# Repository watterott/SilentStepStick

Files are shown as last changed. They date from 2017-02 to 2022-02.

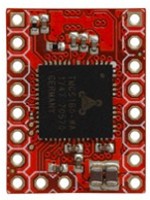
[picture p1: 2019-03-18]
hardware/SilentStepStick-TMC5160_v13.jpg

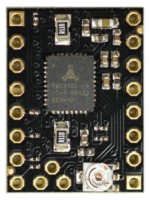
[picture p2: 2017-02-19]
hardware/SilentStepStick-TMC2100_v13.jpg

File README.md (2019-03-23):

# SilentStepStick
The Silent-Step-Stick is a Stepper Motor Driver Board for 2-Phase Motors based on [Trinamic](https://www.trinamic.com) Motor Drivers.

* Hardware compatible with [StepStick](https://reprap.org/wiki/StepStick) and [Pololu A4988](https://www.pololu.com/product/1182)
* [Trinamic](https://www.trinamic.com) stepper motor driver (chopper drive / constant current drive) with
  * Automatic standby current reduction
  * **microPlyer** - microstep interpolator for increased smoothness of microstepping
  * **stealthChop** - for quiet operation and smooth motion
  * **spreadCycle** - highly dynamic motor control chopper
* Open-Source and released under the [Creative Commons Attribution Share-Alike License](https://creativecommons.org/licenses/by-sa/4.0/).
* **[Documentation on learn.watterott.com](https://learn.watterott.com)**

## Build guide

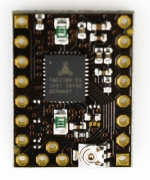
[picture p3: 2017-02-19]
hardware/SilentStepStick-TMC2100_v10.jpg

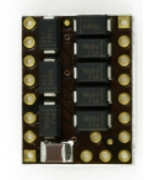
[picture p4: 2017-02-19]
hardware/StepStick-Protector_v10.jpg

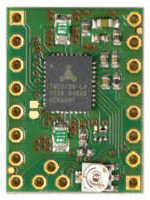
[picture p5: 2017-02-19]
hardware/SilentStepStick-TMC2130_v11.jpg

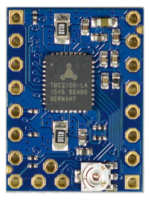
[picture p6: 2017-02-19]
hardware/SilentStepStick-TMC2100_v13_5V.jpg

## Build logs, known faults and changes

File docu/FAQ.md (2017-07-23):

# Frequently Asked Questions

## Is the SilentStepStick 100% compatible with a StepStick or Pololu A4988?
The SilentStepStick is hardware/pin compatible with StepStick and Pololu A4988 drivers.
However the TMC21x0 has different and more settings, which can be set via the CFG/MS pins and the **DIR pin is inverted** (direction).
The TMC21x0 config pins also know three states: low (GND), high (VIO) and open (unconnected).
The TMC2130 can be configured via CFG pins or [SPI](https://en.wikipedia.org/wiki/Serial_Peripheral_Interface_Bus) and the TMC2208 via CFG pins or [UART](https://en.wikipedia.org/wiki/Universal_asynchronous_receiver/transmitter).

## Which operating mode should I use?
For most cases (except a 3D printer extruder) the **1/16 stealthChop** mode (TMC2100: CFG1=open CFG2=open, default on TMC2208) is suitable.
If you have problems like step losses then you can use a [slower acceleration](https://www.youtube.com/watch?v=c3v9E1AwDBE) or a bit higher current setting in stealthChop 
or you can use the more powerful and louder **1/16 spreadCycle** mode (TMC2100: CFG1=GND CFG2=open).

#### Boards with USB Power Supply
Only applicable for SilentStepSticks with variable 3-5V logic voltage (VIO):
If you use a control board with USB power supply (like Arduino + RAMPS) then always ensure that the motor voltage (VM) is present, when you connect the board via USB.
Otherwise the TMC2xxx is not powered via the internal voltage regulator and a high current can flow into VIO or the IOs and this can damage the internal logic.
As safety workaround you can disconnect the 5V signal in the USB cable, so that the board cannot be powered over USB.

#### RAMPS 1.4 and RUMBA Notes
For most cases the **1/16 stealthChop** mode is suitable and we recommend the TMC2100 SilentStepStick with 5V for RAMPS and RUMBA boards, because they use 5V logic.
If you remove all jumpers (or open all switches) for MS1+MS2+MS3 on the RAMPS/RUMBA, then the SilentStepStick TMC2100 driver will be in **1/16 spreadCycle mode** (CFG1=GND CFG2=open), because there is a pull-down resistor on MS1 on the RAMPS/RUMBA.
The pull-down is 100k and in most cases it will set the driver in spreadCycle mode correctly. However if there are problems then short CFG1 to GND or replace the resistor with one which is 30k or less.
If you have not an original [RAMPS 1.4](http://reprap.org/wiki/RAMPS_1.4) or [RUMBA](http://reprap.org/wiki/RUMBA), then your schematics can be different and you have to check the MS-Pin configurations on you board.

## Can I use a stepper motor with a lower voltage than the driver motor supply voltage?
Yes, because the TMC2xxx drivers use a chopper drive circuit to generate a constant current in each winding (motor phase) rather than applying a constant voltage.

## What is the difference between SilentStepSticks with 3-5V and 5V logic voltage?
The SilentStepSticks with a variable logic voltage (VIO) of 3-5V use the internal linear regulator of the TMC2xxx to generate from the motor voltage (VM) a 5V voltage for the internal digital and analog circuit (about 20mA).
Because it is a linear voltage regulator the power dissipation depends on the motor voltage (high motor voltage = high power dissipation/heat).
The 5V logic SilentStepSticks do not use the internal voltage regulator of TMC2xxx and therefor only a 5V supply voltage for VIO is possible and VM has not to be present before VIO.
Further infos about power-up and down can be found [here](https://github.com/watterott/SilentStepStick/blob/master/docu/FAQ.md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).

Power dissipation of the internal voltage regulator:
* 0.1W @ VM=12V
* 0.3W @ VM=24V
* 0.6W @ VM=36V
* 0.8W @ VM=45V

## Is the TMC2130 SilentStepStick in standalone mode like a TMC2100 SilentStepStick?
The configuration for TMC2130 in standalone mode (SPI jumper closed) is set via the CFG pins like the TMC2100.
On the TMC2100 SilentStepSticks the CFG0 pin is set to GND as default and this sets the chopper off time to 140 Tclk (most universal choice).
In contrast on the TMC2130 SilentStepSticks the CFG0 pin (also SDO) is open as default and this sets the chopper off time to 332 Tclk.
On the TMC2130 SilentStepSticks the CFG3 pin is also connected to the pin header and should be left unconnected/open (external reference voltage on AIN) in standalone mode.

## Where can I find more information on the settings and operation modes?
More information can be found in the [SilentStepStick schematics (PDF files)](https://github.com/watterott/SilentStepStick/tree/master/hardware) and
[TMC2100 datasheet](http://www.trinamic.com/products/integrated-circuits/details/tmc2100/),
[TMC2130 datasheet](http://www.trinamic.com/products/integrated-circuits/details/tmc2130/) or
[TMC2208 datasheet](http://www.trinamic.com/products/integrated-circuits/details/tmc2208-la/).

A configuration tool for the TMC2208 can be found [here](https://github.com/watterott/SilentStepStick/tree/master/software/ScriptCommunicator#tmc2208-configurator).

Detailed information about the operating modes:
[stealthChop](https://www.trinamic.com/technology/adv-technologies/stealthchop/) and
[spreadCycle](https://www.trinamic.com/technology/adv-technologies/spreadcycle/).

#### Infos and Installation Guides for 3D Printers
* General: [English](http://reprap.org/wiki/TMC2100),
           [German](http://reprap.org/wiki/TMC2100/de),
           [French](http://reso-nance.org/wiki/materiel/silentstepstick/accueil),
           [Russian](http://3deshnik.ru/blogs/akdzg/chto-zhe-delat-belami-tmc2100),
           [Japanese](http://3dp0.com/silentstepstick)
* [Ultimaker UMO + TMC2100 (English)](https://ultimaker.com/en/community/11571-step-by-step-installation-of-silentstepstick-drivers-on-umo)
* [Ultimaker UMO + TMC2130 (English)](https://ultimaker.com/en/community/20090-step-by-step-installation-of-sss-tmc2130-on-umo)
* [TMC2130 (English)](http://hackaday.com/2016/09/30/3d-printering-trinamic-tmc2130-stepper-motor-drivers-shifting-the-gears/)

## How to set the stepper motor current?
The best way to set the motor current is by measuring the voltage on the ```Vref``` pin (0...2.5V) and
adjusting the voltage with the potentiometer.
The maximum motor current is 1.77A RMS and is set via the 0.11Ohm sense resistors.

```Irms = (Vref * 1.77A) / 2.5V = Vref * 0.71```

```Vref = (Irms * 2.5V) / 1.77A = Irms * 1.41 = Imax```

```Vref``` -> Voltage on Vref pin

```Irms``` -> RMS (Root Mean Square) current per phase (Irms = Imax / 1.41)

```Imax``` -> Maximum current per phase (Imax = Irms * 1.41)

**Example:**
A voltage of 1.0V on Vref sets the motor current to 0.71A RMS.

**Note:**
On some stepper motor drivers the maximum current (e.g. A4988) is set via Vref and on others the RMS current (e.g. TMC2100).
The Trinamic drivers have an automatic thermal shutdown (at about 150°C) if the chip gets to hot.

## What to consider when turning the power supply on or off?
**Power on:**

*SilentStepSticks with variable 3-5V logic voltage:*
The motor voltage VM should come up first and then the logic voltage VIO, because the internal logic of the TMC2xxx driver is powered from VM.

*SilentStepSticks with 5V logic voltage:*
There is no special power up sequence needed.

Only after the logic voltage VIO is present and stable, the driver inputs (STEP, DIR, EN, CFG...) can be driven with a high level.

A step pulse (moving) should only be done after the motor voltage VM is present and stable.

Because the motor voltage VM is a strong power supply with a high voltage, also ensure that there cannot occur voltage spikes on power up.
See [Pololu: Understanding Destructive LC Voltage Spikes](https://www.pololu.com/docs/0J16/all).

**Power off:**

*SilentStepSticks with variable 3-5V logic voltage:*
The logic voltage VIO should turned off at first and then the motor voltage VM, because the internal logic of the TMC2xxx driver is powered from VM.

*SilentStepSticks with 5V logic voltage:*
There is no special power off sequence needed.

If the motor is running/moving, then it is not allowed to switch off the power supply. Always make sure that the motor stands still on shutting down, otherwise the TMC2xxx driver can get damaged.

An **emergency stop** can be realized, when the EN/CFG6 pin is set to VIO (high). This will switch off all power drivers and will put the motor into freewheeling.
See also: [SilentStepStick Protector with flyback diodes](https://github.com/watterott/SilentStepStick#shop)

## The motor makes noise in spreadCycle mode when it is not moving?
A motor supply voltage of 12V is in most cases to low and in general the sound gets quieter if the motor supply voltage is above 18V.
As workaround it is possible to activate the TMC21x0 automatic current reduction on standstill. This is done by not connecting the EN pin (EN=open).

## How to control the Trinamic stepper motor driver?
The SilentStepStick has a normal step+direction interface.
You set the direction with the DIR pin and on every pulse on the STEP pin the motor will move one step.
Here you can find an [Arduino example](https://github.com/watterott/SilentStepStick/tree/master/software) and [Arduino library](http://www.airspayce.com/mikem/arduino/AccelStepper/) (interface=DRIVER).

## Is it possible to connect the CFG pins from different SilentStepSticks?
It is possible to connect the CFG pins from two or more driver boards.
However then the pin state can only be GND (low) or VIO (high). The open state (unconnected) is not possible in this configuration.

## Why is the Trinamic driver chip on the bottom PCB side?
The TMC2xxx chip has a thermal pad on the bottom which is soldered to the PCB.
So the thermal resistance via the chip bottom is better than via the chip top.
That is why the chip is on the bottom PCB side.
A heat sink can be placed directly on the PCB.
Further infos [here](https://www.youtube.com/watch?time_continue=145&v=mYuZqx8xwTg).

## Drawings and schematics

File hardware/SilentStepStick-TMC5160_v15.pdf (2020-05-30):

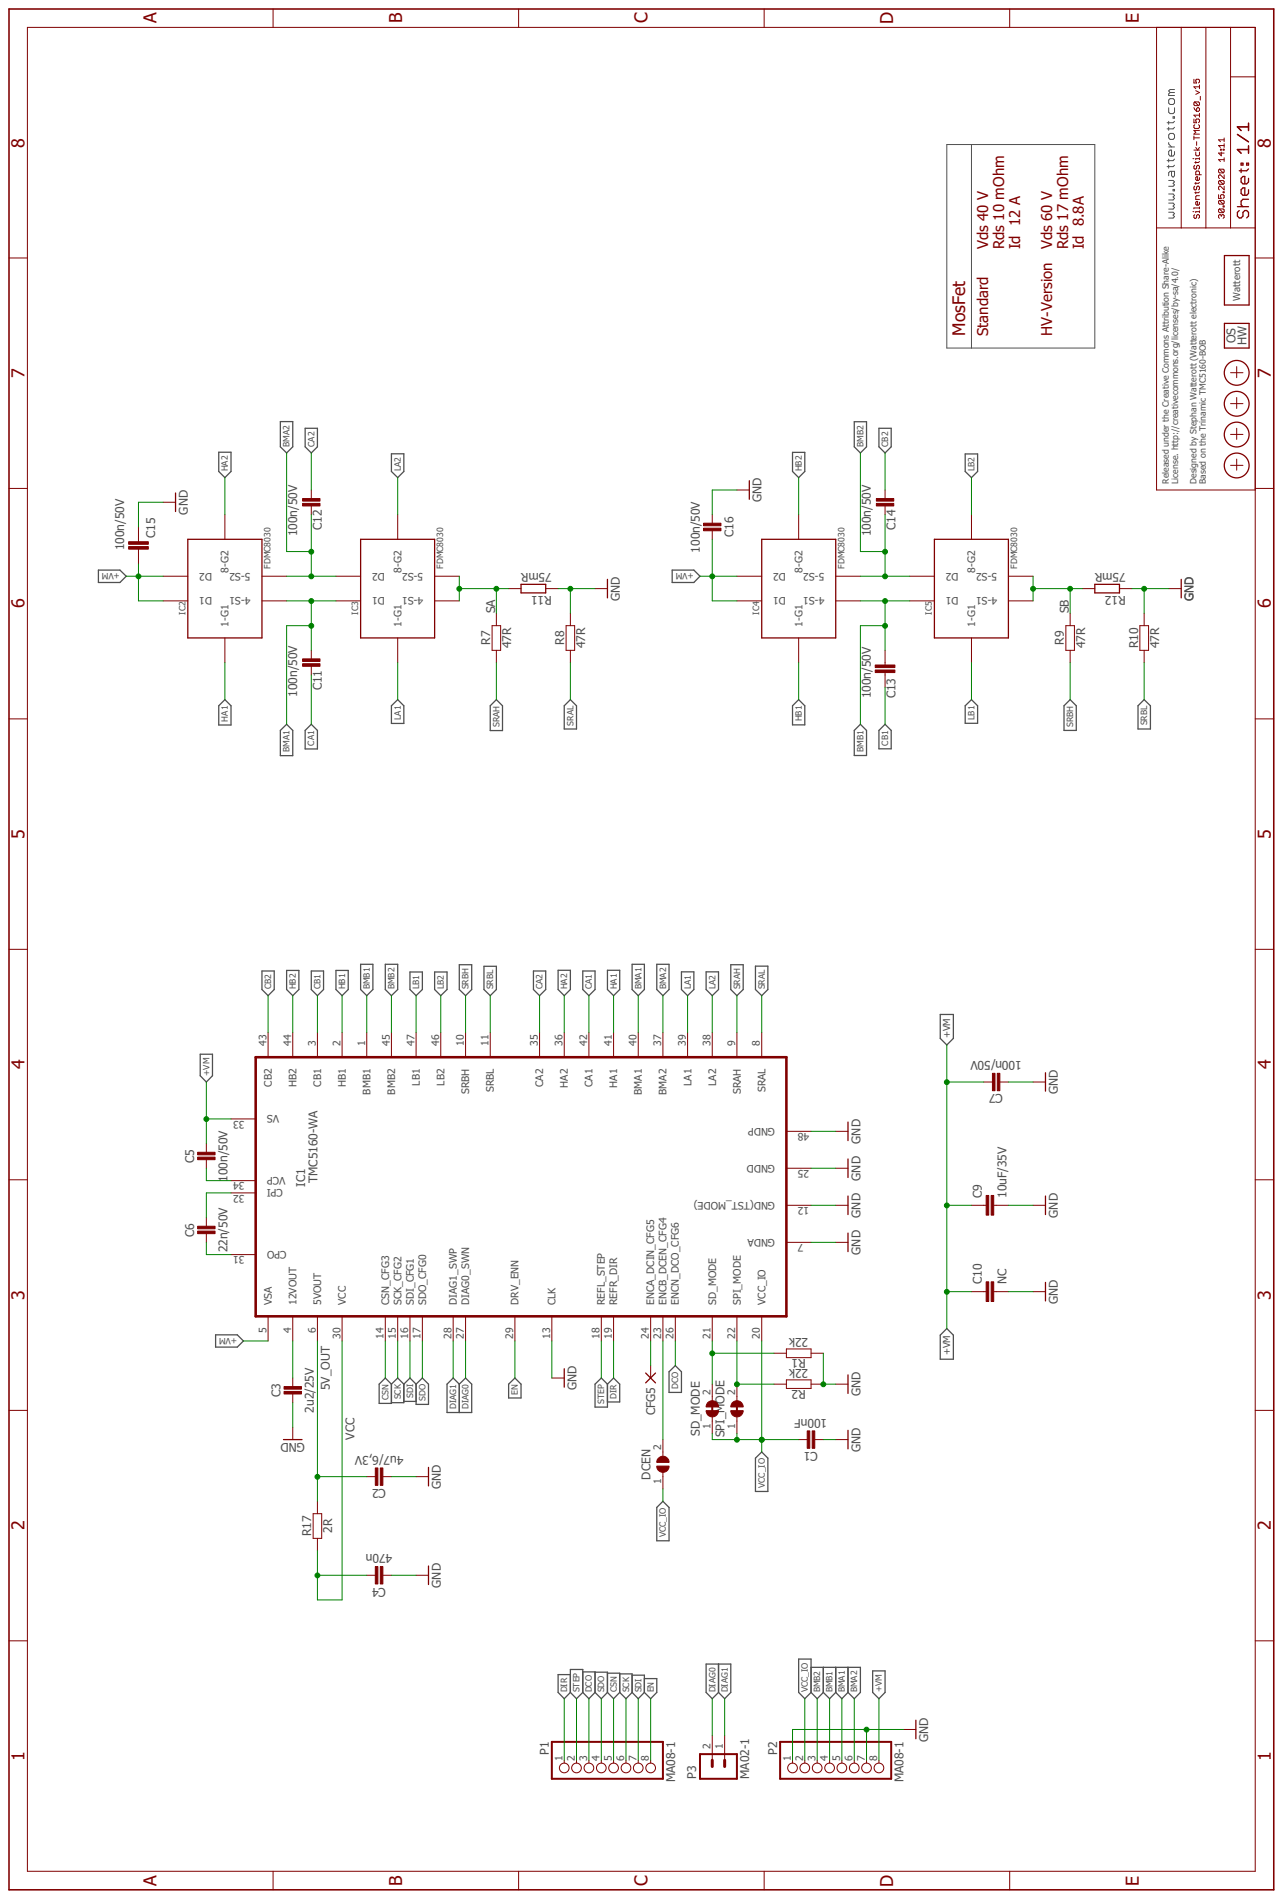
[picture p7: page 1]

MosFet Standard HV-Version

Released under the Creative Commons Attribution Share-Alike

License. http://creativecommons.org/licenses/by-sa/4.0/ Designed by Stephan Watterott (Watterott electronic) Based on the Trinamic TMC5160-BOB

10uF/35V NC GND GND GND

GND GND

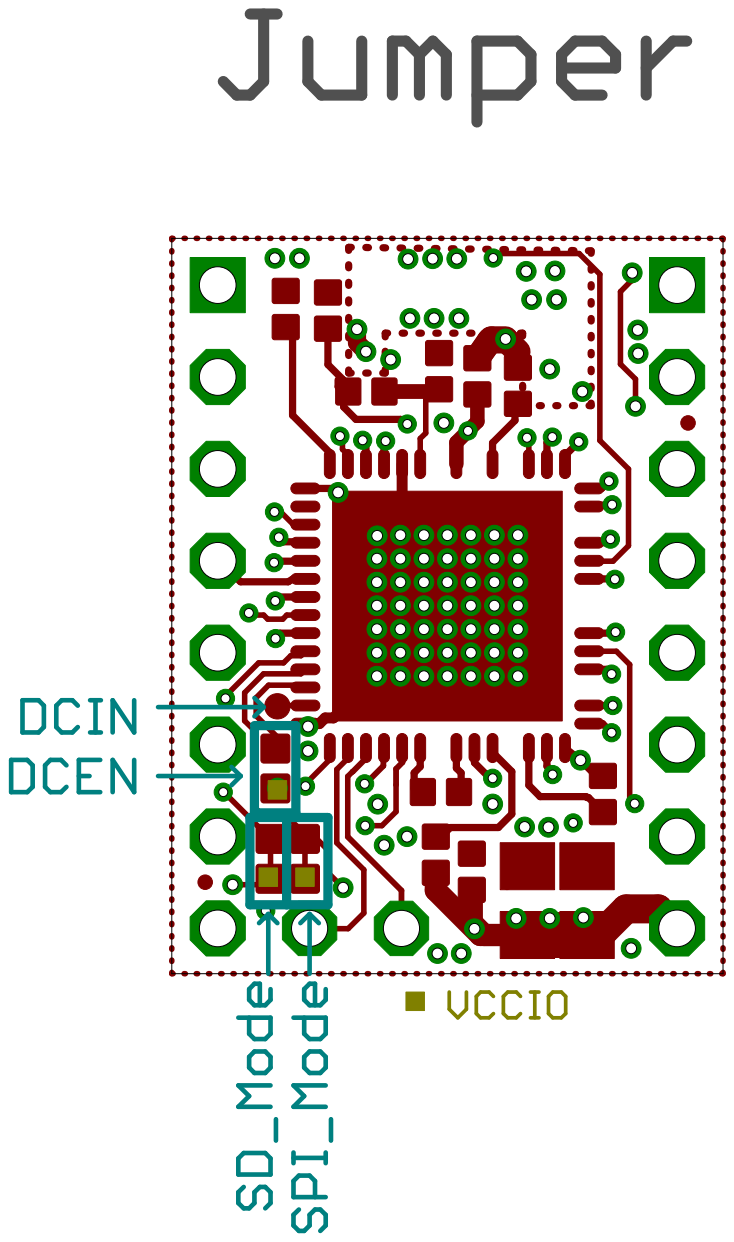
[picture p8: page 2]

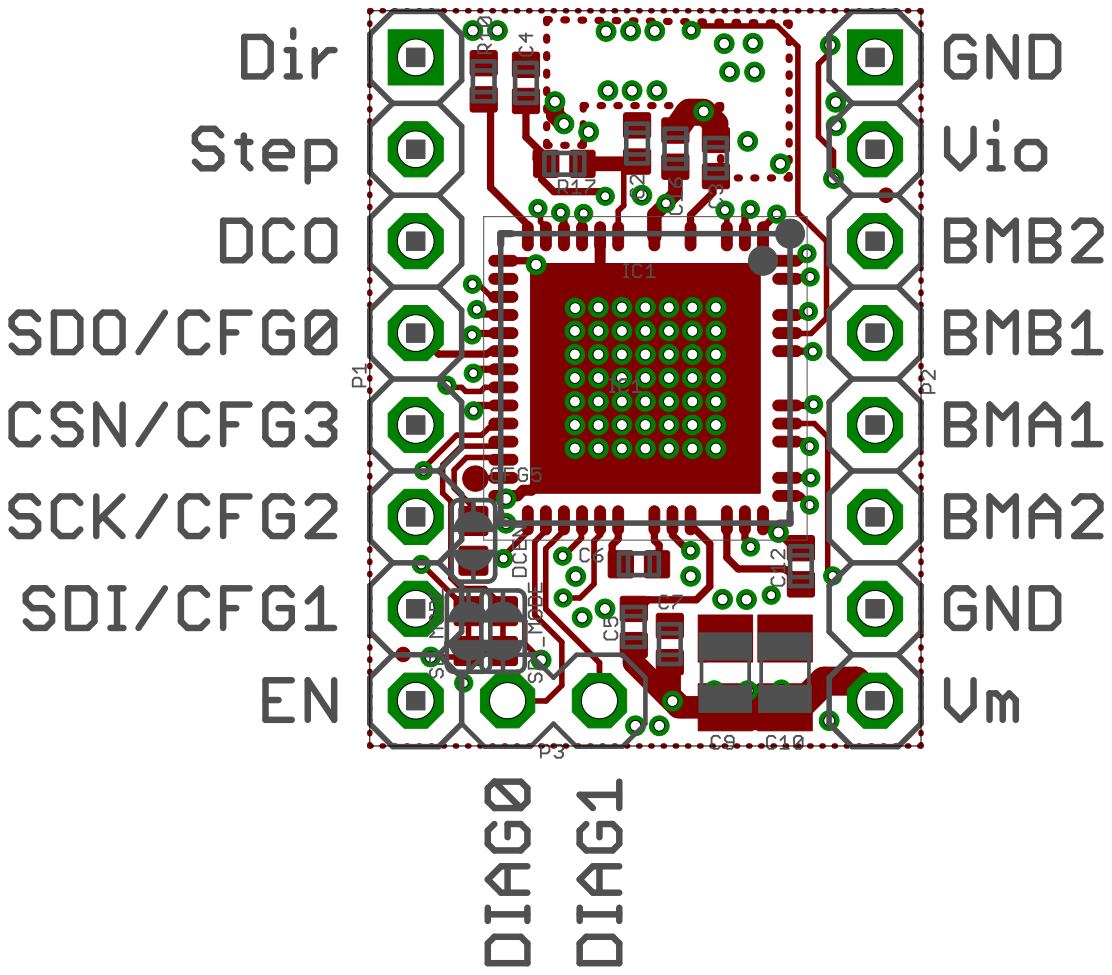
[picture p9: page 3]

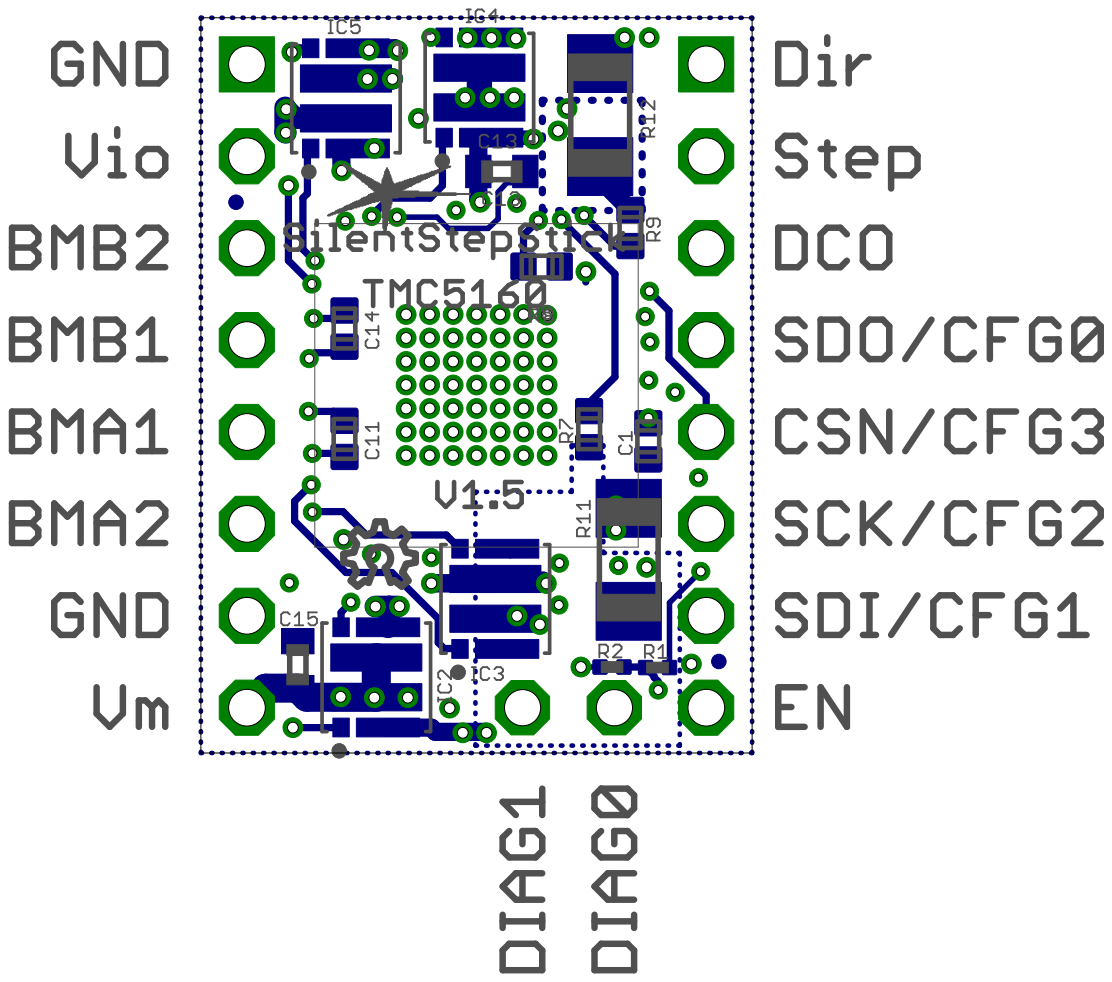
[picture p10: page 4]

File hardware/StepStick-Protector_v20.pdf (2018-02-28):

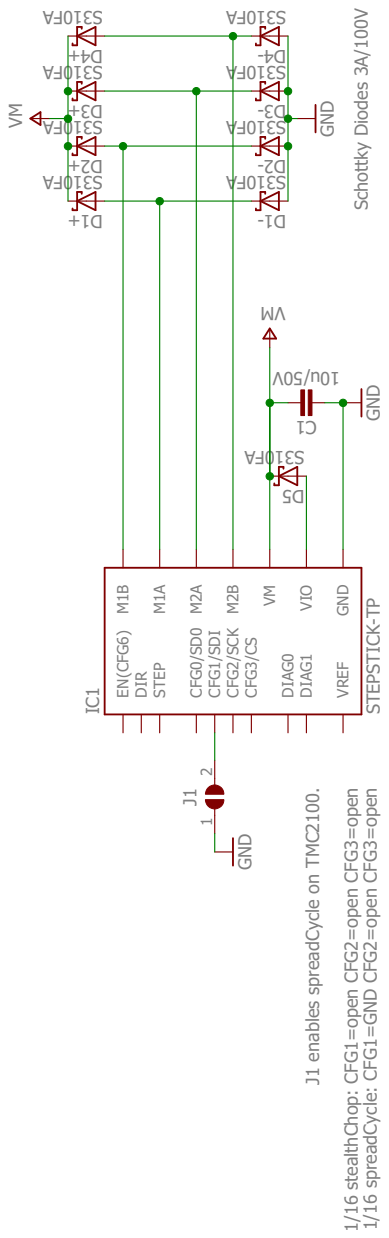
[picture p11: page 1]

Schottky Diodes 3A/100V J1 enables spreadCycle on TMC2100. 1/16 stealthChop: CFG1=open CFG2=open CFG3=open 1/16 spreadCycle: CFG1=GND CFG2=open CFG3=open AF013S AF013S AF013S AF013S AF013S AF013S AF013S AF013S GNDVM MV GND V05/ u01 GND AF013S Released under the Creative Commons Attribution Share-Alike License http://creativecommons.org/licenses/by-sa/4.0/ Designed by Andreas Watterott (Watterott electronic) IC1 STEPSTICK-TP DIR STEP CFG1/SDI CFG2/SCK CFG3/CS DIAG0 EN(CFG6) VMVIO GND M1A DIAG1 M2A M1B M2B VREF CFG0/SD0 +1D +2D +3D +4D - 1D - 2D - 3D - 4D 1C J1 2 1 5D Watterott ABCD 1 2 3 4 5 6 ABCD 1 2 3 4 5 6 OSHW

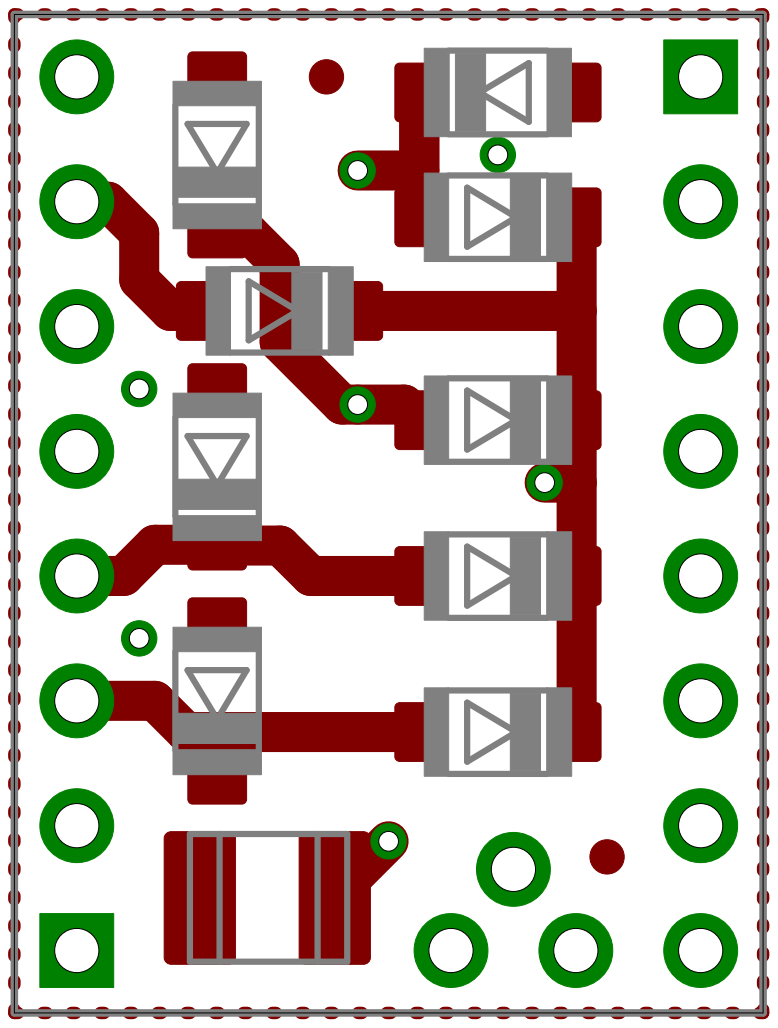
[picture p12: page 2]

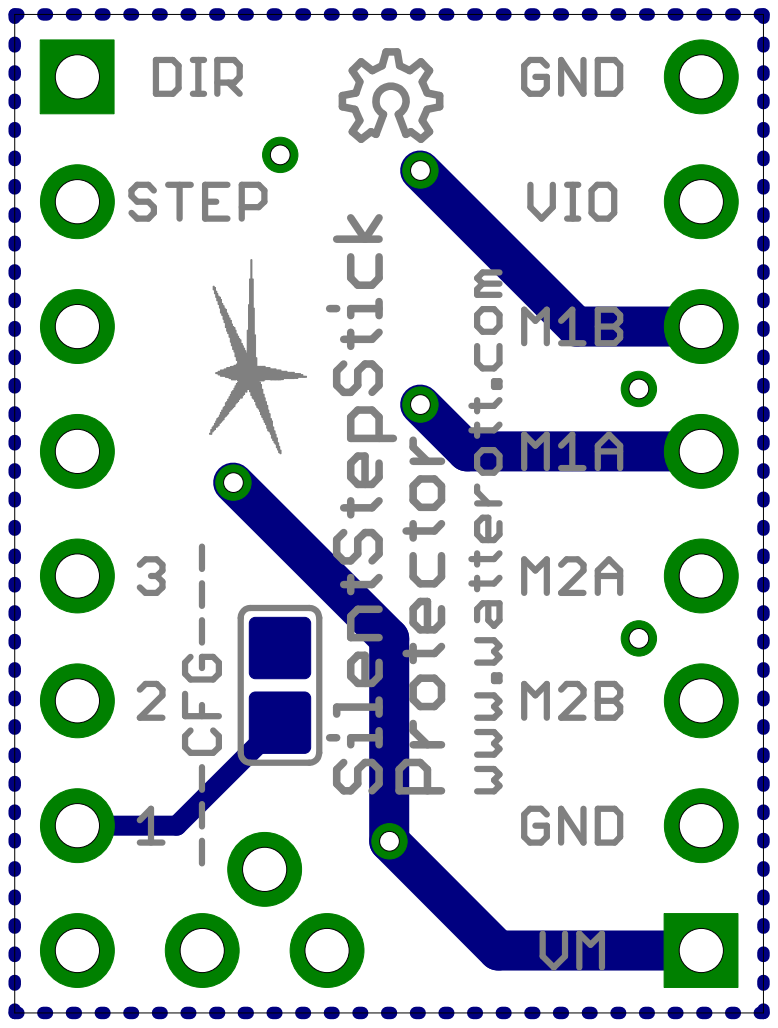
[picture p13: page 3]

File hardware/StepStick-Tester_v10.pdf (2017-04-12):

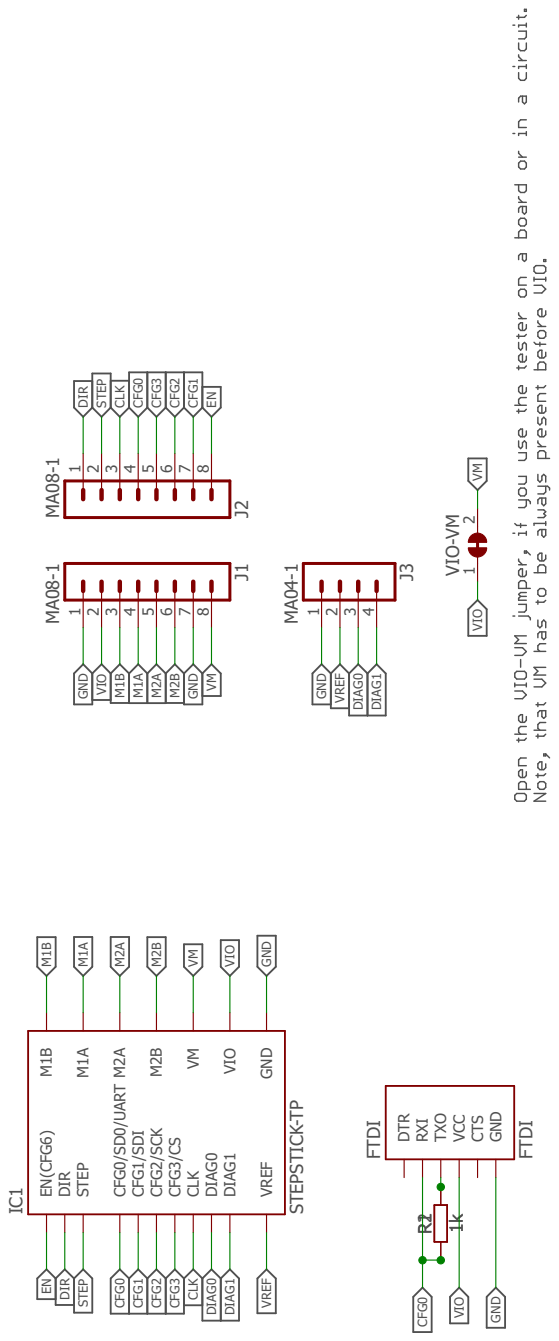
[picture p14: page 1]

MA08-1 MA08-1 1k MA04-1Released under the Creative Commons At ribution Share-Alike License http://creativecommons.org/licenses/by-sa/4.0/ Designed by Andreas Watterott (Watterott electronic) IC1 STEPSTICK-TP DIR STEP CFG1/SDI CFG2/SCK CFG3/CS DIAG0 EN(CFG6) VMVIO GND M1A DIAG1 M2A M1B M2B VREF CFG0/SD0/UART CLK FTDI FTDI DTR RXI TXO VCC CTS GND J1 12345678 J2 12345678 R1 VIO-VM2 1 R2 J3 1234 CFG1 CFG1 STEP STEP DIR DIR EN EN CFG2 CFG2 CFG3 CFG3 DIAG0 DIAG0 DIAG1 DIAG1 VREF VREF CLK CLK M1B M1B M1A M1A M2A M2A M2B M2B VM VM VM VIO VIO VIO VIO GND GND GND GND GND CFG0 CFG0 CFG0 ABCD 1 2 3 4 5 6 ABCD 1 2 3 4 5 6 OSHW Watterott

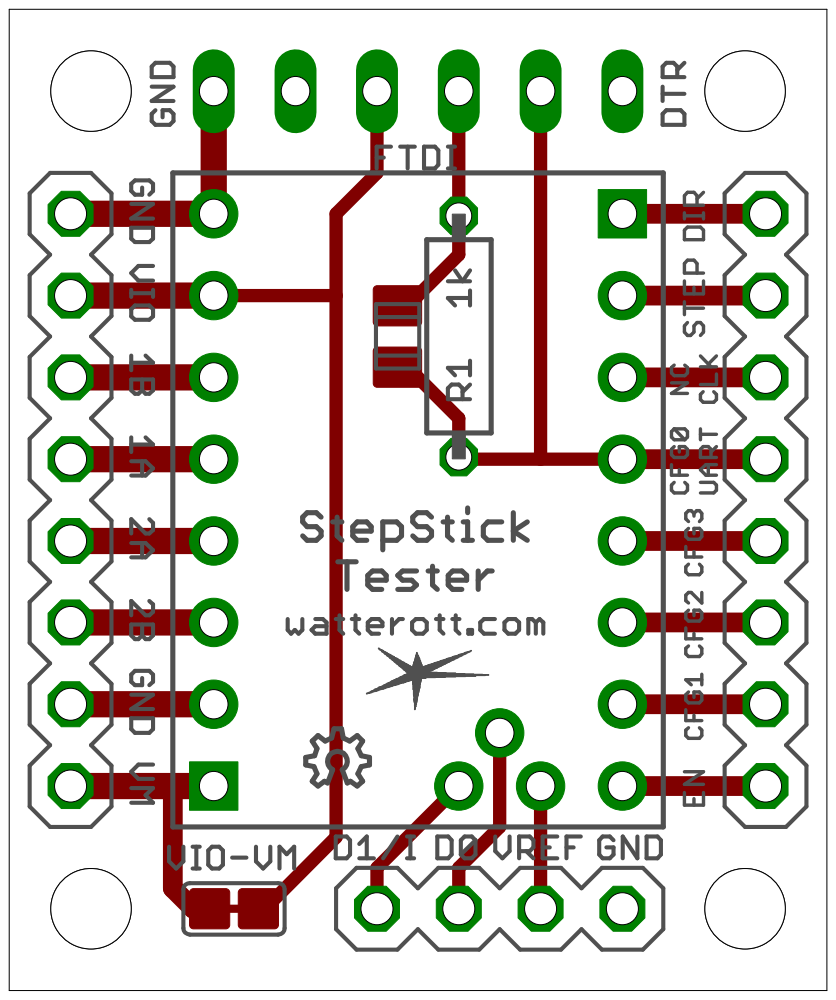
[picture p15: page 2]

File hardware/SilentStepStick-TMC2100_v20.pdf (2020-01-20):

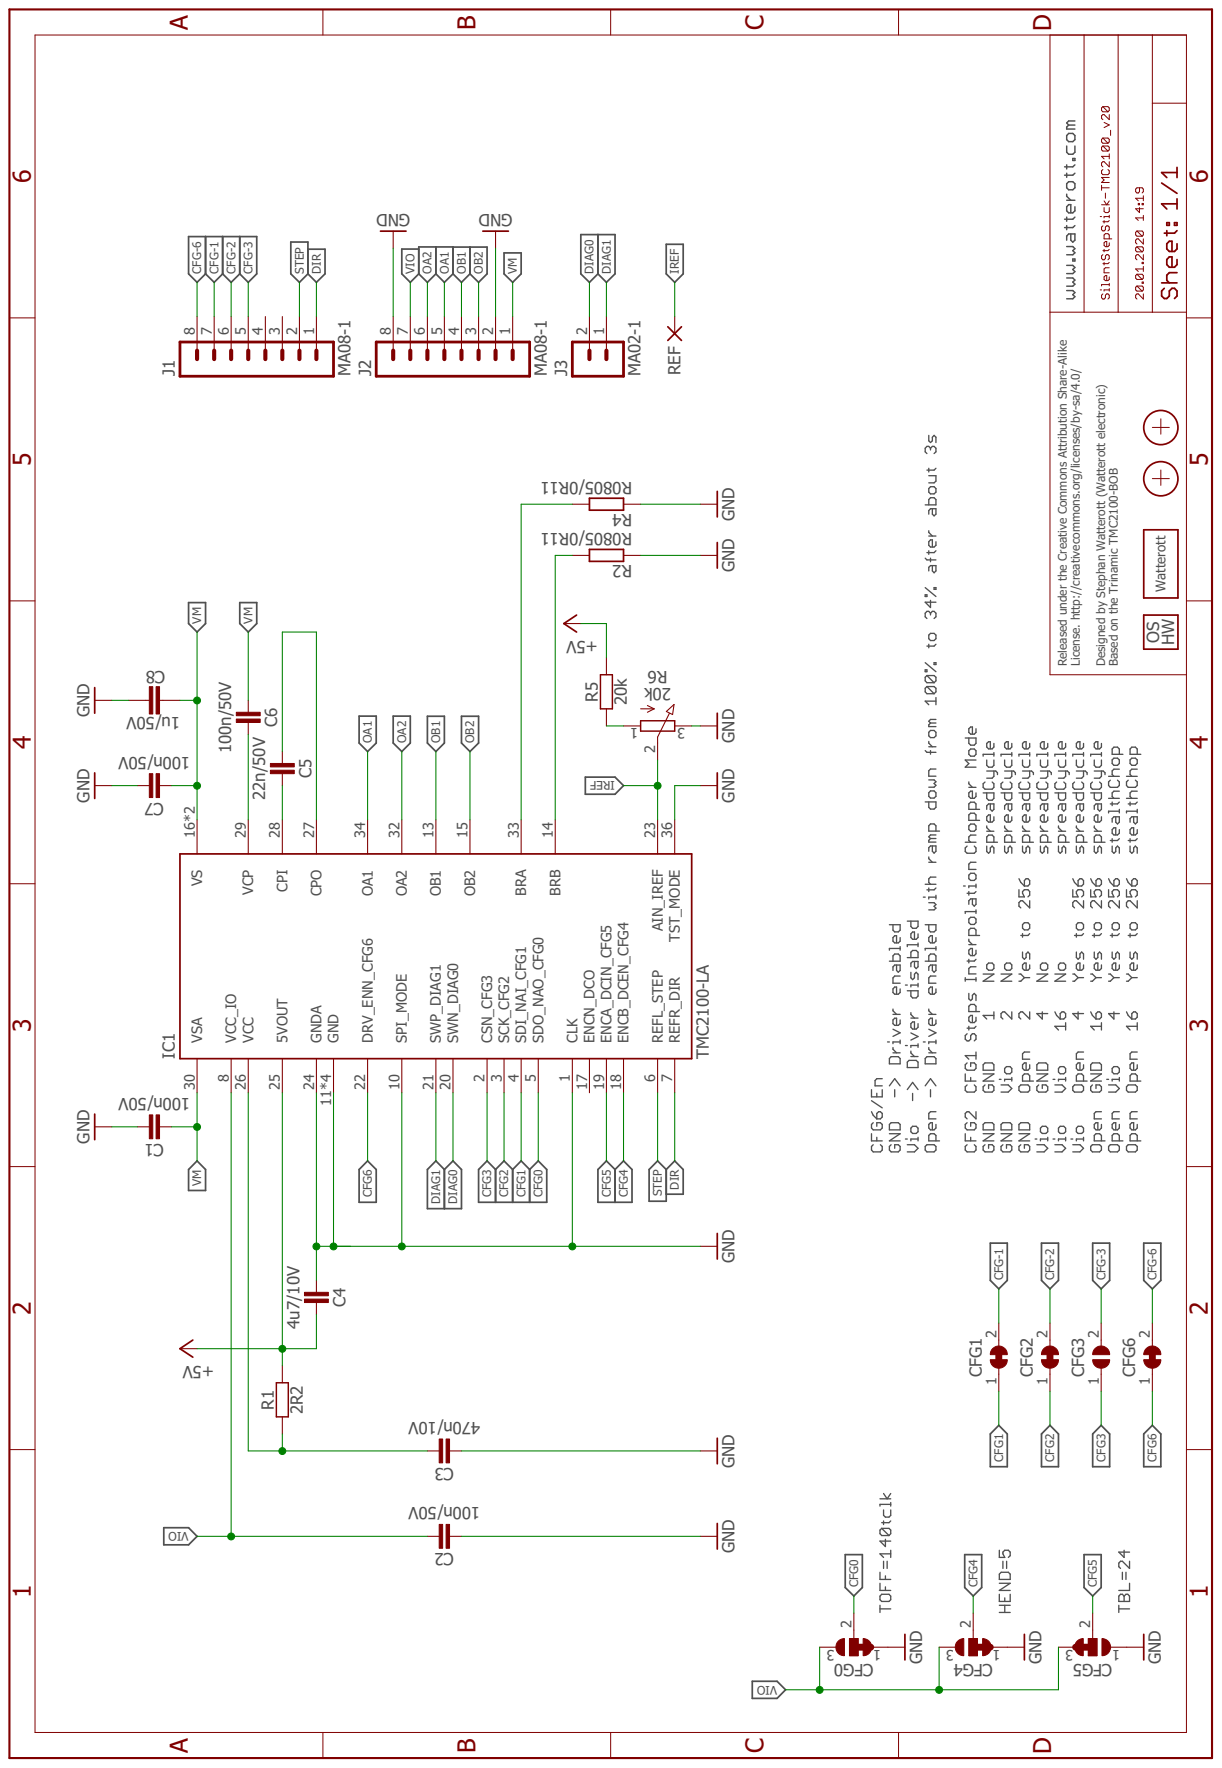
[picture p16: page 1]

Released under the Creative Commons Attribution Share-Alike

License. http://creativecommons.org/licenses/by-sa/4.0/ Designed by Stephan Watterott (Watterott electronic) Based on the Trinamic TMC2100-BOB

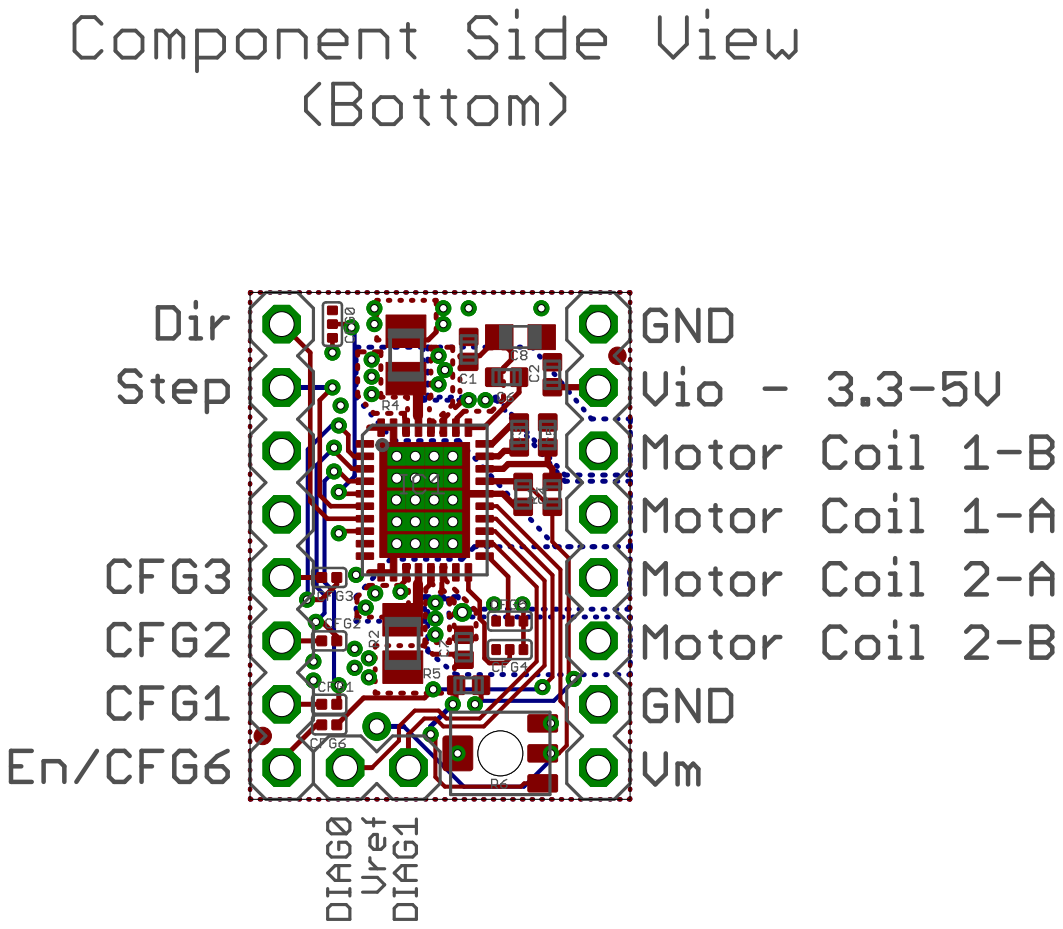
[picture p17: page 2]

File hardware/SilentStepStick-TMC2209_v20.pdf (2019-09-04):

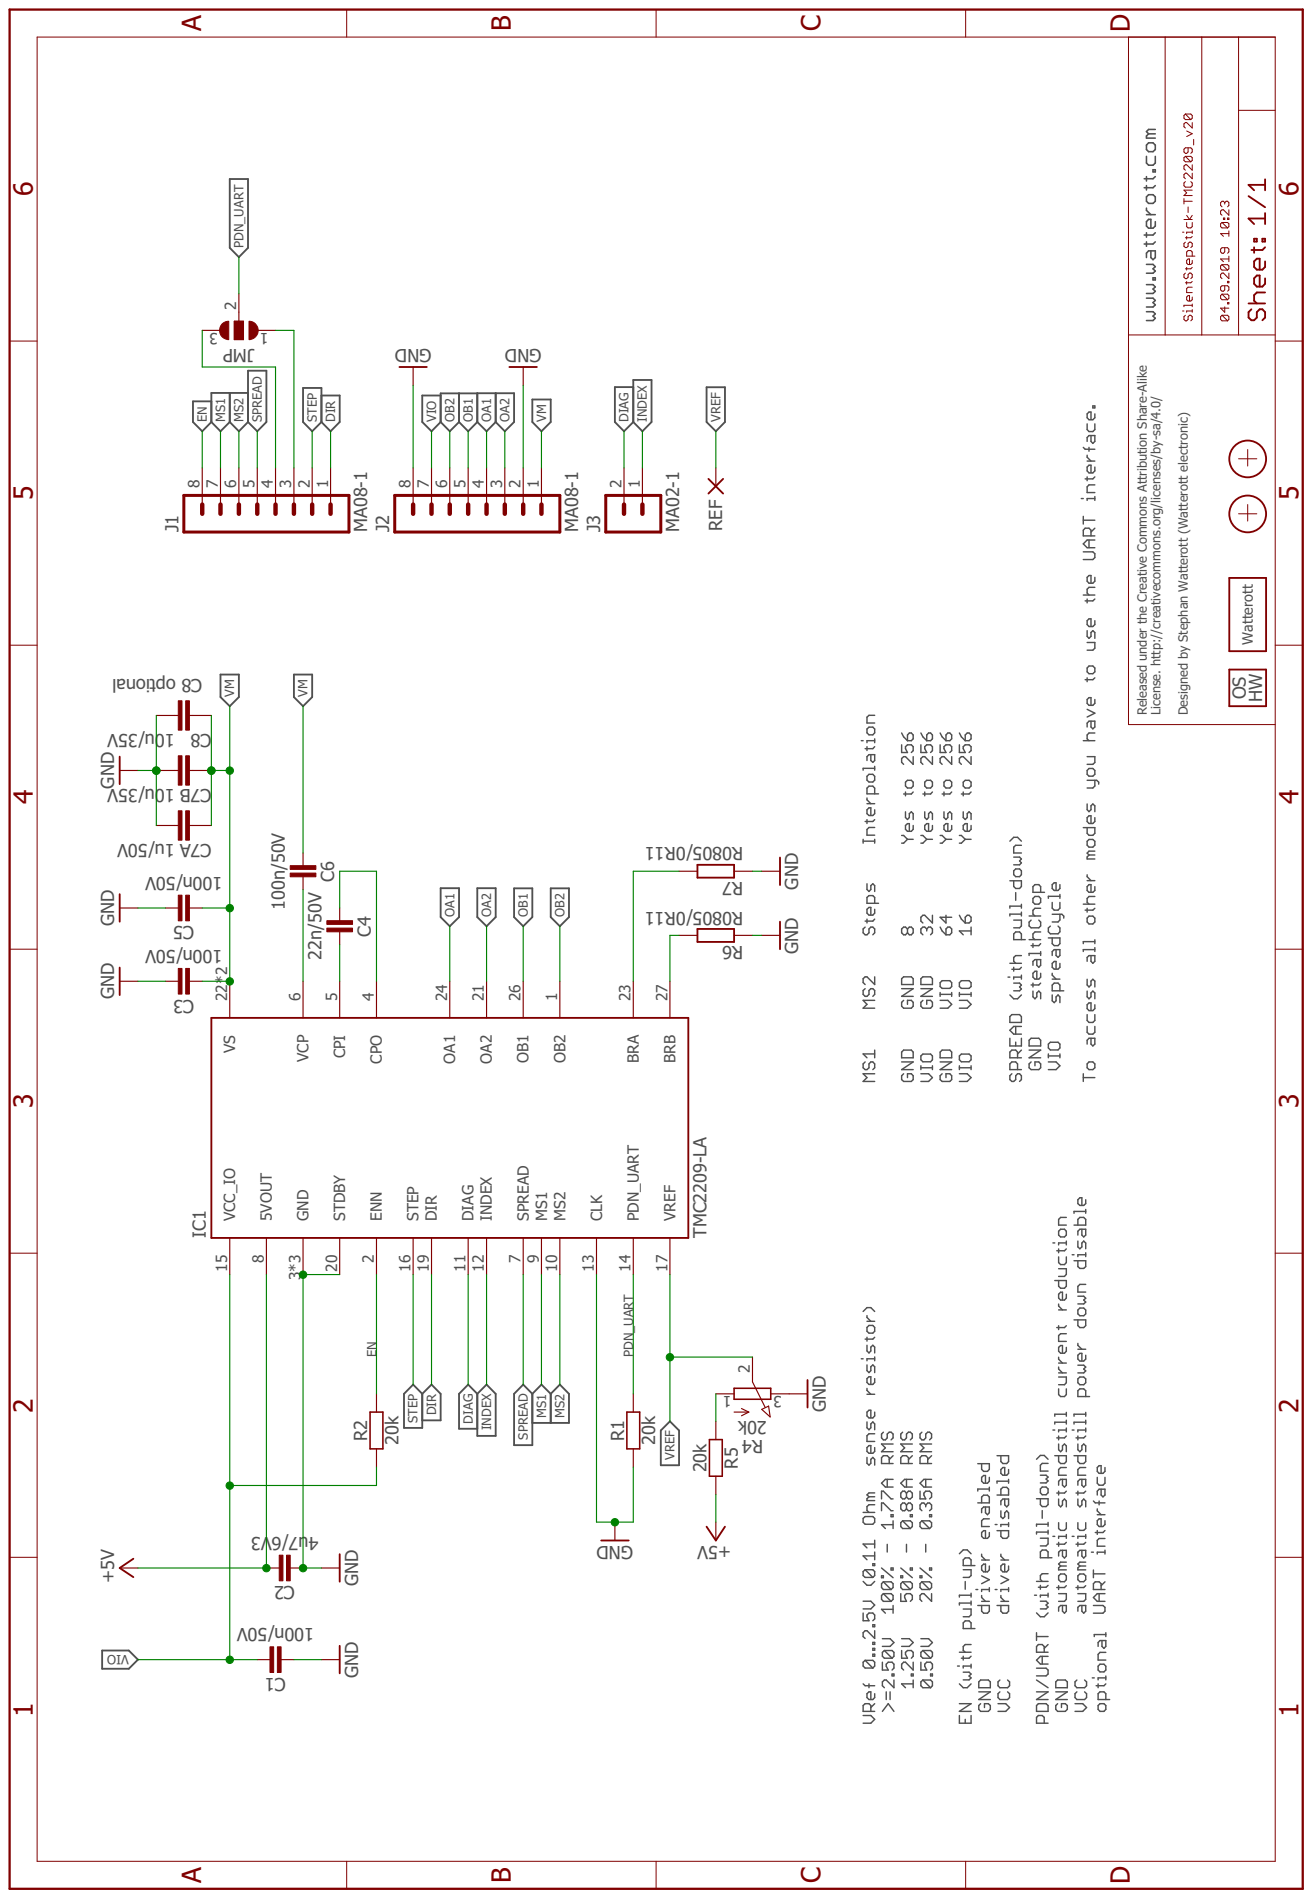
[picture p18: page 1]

Released under the Creative Commons Attribution Share-Alike

License. http://creativecommons.org/licenses/by-sa/4.0/ Designed by Stephan Watterott (Watterott electronic)


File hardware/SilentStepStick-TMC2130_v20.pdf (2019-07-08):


Released under the Creative Commons Attribution Share-Alike

License. http://creativecommons.org/licenses/by-sa/4.0/ Designed by Stephan Watterott (Watterott electronic) Based on the Trinamic TMC2100-BOB


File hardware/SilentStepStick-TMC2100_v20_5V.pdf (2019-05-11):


Released under the Creative Commons Attribution Share-Alike

License. http://creativecommons.org/licenses/by-sa/4.0/ Designed by Stephan Watterott (Watterott electronic) Based on the Trinamic TMC2100-BOB


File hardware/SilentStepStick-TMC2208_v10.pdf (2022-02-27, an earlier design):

DNG DNG GND GND 11R0/ 5080R 11R0/ 5080R GND GND GND V05/ u1 GND +5V V5 + k02 V05/ n001 3V6/ 7u4 V05/ n001 100n/50V 22n/50V 20k DNG20k 20k 20k V05/ n001 GND GND Released under the Creative Commons Attribution Share-Alike License. http://creativecommons.org/licenses/by-sa/4.0/ Designed by Stephan Watterott (Watterott electronic) 87654321JP1 87654321JP2 6R7R 7C 4R 1 3 2 1JP3 1JP4 1JP5 1C2C 3C C6 C4 R5 CLK 13 MS1 9 MS2 10 GND 3*3 PDN_UART 14 STEP 16 DIR 19 VCC_IO 15 OB1 26 BRB 27 OB2 1 VS 22*2 INDEX 12 DIAG 11 ENN 2 VREF 17 5VOUT 8 CPO 4 CPI 5 VCP 6 OA2 21 BRA 23 OA1 24 IC1 TMC2208 R3 R1R2 J1 2 1 J2 2 1 5C DIAG DIAG INDEX INDEX STEP STEP DIR DIR VM VMVM OA1 OA1 OA2 OA2 OB2 OB2 OB1 OB1 VIO OI V VREF VREF MS1 MS1 MS2 MS2 CLK CLK PDN_UART PDN_UART EN EN OSHW Watterott ABCD 1 2 3 4 5 6 ABCD 1 2 3 4 5 6


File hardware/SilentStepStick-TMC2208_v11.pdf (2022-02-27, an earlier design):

DNG DNG GND GND 11R0/ 5080R 11R0/ 5080R GND GND GND V05/ u1 GND +5V V5 + k02 V05/ n001 3V6/ 7u4 V05/ n001 100n/50V 22n/50V 20k DNG20k 20k 20k V05/ n001 GND GND Released under the Creative Commons Attribution Share-Alike License. http://creativecommons.org/licenses/by-sa/4.0/ Designed by Stephan Watterott (Watterott electronic) 87654321JP1 87654321JP2 6R7R 7C 4R 1 3 2 1JP3 1JP4 1JP5 1C2C 3C C6 C4 R5 CLK 13 MS1 9 MS2 10 GND 3*3 PDN_UART 14 STEP 16 DIR 19 VCC_IO 15 OB1 26 BRB 27 OB2 1 VS 22*2 INDEX 12 DIAG 11 ENN 2 VREF 17 5VOUT 8 CPO 4 CPI 5 VCP 6 OA2 21 BRA 23 OA1 24 IC1 TMC2208 R3 R1R2 J1 2 1 5C 2J 3 1 2 DIAG DIAG INDEX INDEX STEP STEP DIR DIR VM VMVM OA1 OA1 OA2 OA2 OB2 OB2 OB1 OB1 VIO OI V VREF VREF MS1 MS1 MS2 MS2 CLK CLK PDN_UART PDN_UART EN EN OSHW Watterott ABCD 1 2 3 4 5 6 ABCD 1 2 3 4 5 6


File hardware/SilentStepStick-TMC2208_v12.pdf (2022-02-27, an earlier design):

DNG DNG GND GND 11R0/ 5080R 11R0/ 5080R GND GND GND V05/ u1 GND +5V V5 + k02 V05/ n001 3V6/ 7u4 V05/ n001 100n/50V 22n/50V 20k DNG20k 20k 20k V05/ n001 GND GND Released under the Creative Commons Attribution Share-Alike License. http://creativecommons.org/licenses/by-sa/4.0/ Designed by Stephan Watterott (Watterott electronic) 87654321JP1 87654321JP2 6R7R 7C 4R 1 3 2 1JP3 1JP4 1JP5 1C2C 3C C6 C4 R5 CLK 13 MS1 9 MS2 10 GND 3*3 PDN_UART 14 STEP 16 DIR 19 VCC_IO 15 OB1 26 BRB 27 OB2 1 VS 22*2 INDEX 12 DIAG 11 ENN 2 VREF 17 5VOUT 8 CPO 4 CPI 5 VCP 6 OA2 21 BRA 23 OA1 24 IC1 TMC2208 R3 R1R2 J1 2 1 5C 2J 3 1 2 DIAG DIAG INDEX INDEX STEP STEP DIR DIR VM VMVM OA1 OA1 OA2 OA2 OB2 OB2 OB1 OB1 VIO OI V VREF VREF MS1 MS1 MS2 MS2 CLK CLK PDN_UART PDN_UART EN EN OSHW Watterott ABCD 1 2 3 4 5 6 ABCD 1 2 3 4 5 6


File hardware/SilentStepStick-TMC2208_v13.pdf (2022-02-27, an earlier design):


Released under the Creative Commons Attribution Share-Alike

STEP STEP DIR DIR

License. http://creativecommons.org/licenses/by-sa/4.0/ Designed by Stephan Watterott (Watterott electronic)


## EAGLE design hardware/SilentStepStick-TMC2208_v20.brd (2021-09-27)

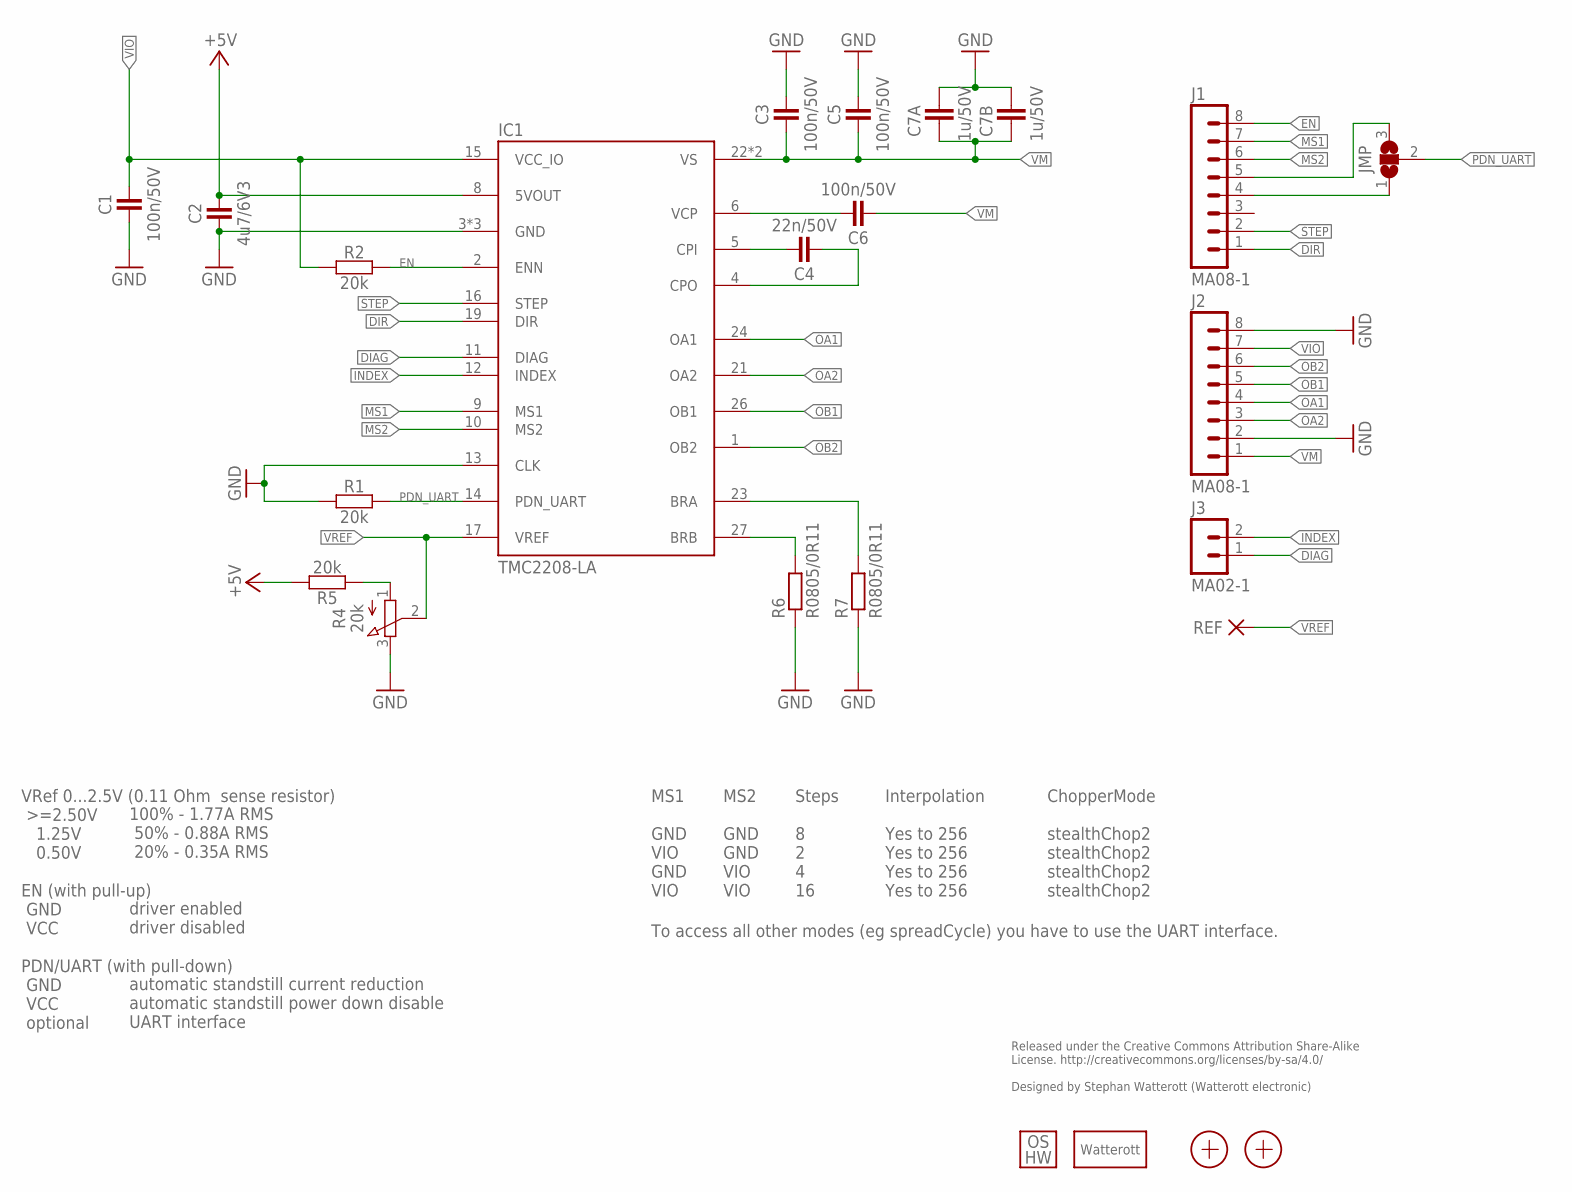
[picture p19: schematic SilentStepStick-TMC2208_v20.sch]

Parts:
C1, C3, C5, C6: 100n/50V; C0402
C2: 4u7/6V3; C0402
C4: 22n/50V; C0402
C7A: 1u/50V; C0805
C7B: 1u/50V; C1206
IC1: TMC2208-LA; QFN28-PAD
J1, J2: MA08-1
J3: MA02-1
JMP: JUMPER3-0402-NC; JUMPER3-0402_NC
LOGO3: LOGO_SPARK-2; SPARK_2MM
LOGO4: LOGO_OSHW-2; OSHW_2MM
R1, R2, R5: 20k; C0402
R4: 20k; POT_EVM3R
R6, R7: R0805/0R11; M0805
REF: PAD-0.6-1.1
X1, X2: PASSER-04; PASSER_04MM

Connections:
+5V: C2.2, IC1.8 (5VOUT), R5.2
BRA: IC1.23 (BRA), R7.2
BRB: IC1.27 (BRB), R6.2
CPI: C4.2, IC1.5 (CPI)
CPO: C4.1, IC1.4 (CPO)
DIAG: IC1.11 (DIAG), J3.1
DIR: IC1.19 (DIR), J1.1
EN: IC1.2 (ENN), J1.8, R2.2
GND: C1.1, C2.1, C3.2, C5.2, C7A.2, C7B.2, IC1.3 (GND), IC1.13 (CLK), IC1.18 (GND), IC1.TP (GND), J2.2, J2.8, R1.1, R4.3 (E), R6.1, R7.1
INDEX: IC1.12 (INDEX), J3.2
MS1: IC1.9 (MS1), J1.7
MS2: IC1.10 (MS2), J1.6
unnamed: J1.5, JMP.3
unnamed: J1.4, JMP.1
OA1: IC1.24 (OA1), J2.4
OA2: IC1.21 (OA2), J2.3
OB1: IC1.26 (OB1), J2.5
OB2: IC1.1 (OB2), J2.6
PDN_UART: IC1.14 (PDN_UART), JMP.2, R1.2
STEP: IC1.16 (STEP), J1.2
VCP: C6.2, IC1.6 (VCP)
VIO: C1.2, IC1.15 (VCC_IO), J2.7, R2.1
VM: C3.1, C5.1, C6.1, C7A.1, C7B.1, IC1.22 (VS), IC1.28 (VS), J2.1
VREF: IC1.17 (VREF), R4.2 (S), REF.1
VREF1: R4.1 (A), R5.1

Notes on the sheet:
Released under the Creative Commons Attribution Share-Alike License. http://creativecommons.org/licenses/by-sa/4.0/ Designed by Stephan Watterott (Watterott electronic)
VRef 0...2.5V (0.11 Ohm sense resistor) >=2.50V 1.25V 0.50V EN (with pull-up) GND VCC PDN/UART (with pull-down) GND VCC optional
100% - 1.77A RMS 50% - 0.88A RMS 20% - 0.35A RMS driver enabled driver disabled automatic standstill current reduction automatic standstill power down disable UART interface
MS1 GND VIO GND VIO
MS2 GND GND VIO VIO
Steps 8 2 4 16
Interpolation Yes to 256 Yes to 256 Yes to 256 Yes to 256
ChopperMode stealthChop2 stealthChop2 stealthChop2 stealthChop2
To access all other modes (eg spreadCycle) you have to use the UART interface.

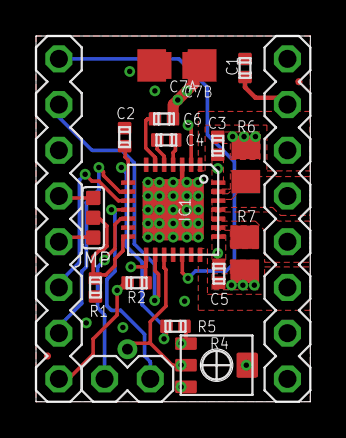
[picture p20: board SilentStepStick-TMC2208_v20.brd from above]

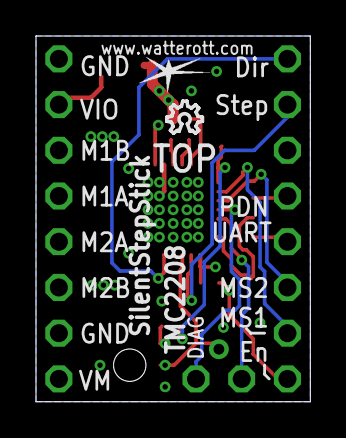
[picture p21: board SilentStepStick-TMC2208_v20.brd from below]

Board: 4 copper layers, 15.2 x 20.3 mm, 24 parts (2 on the bottom side), 25 nets.

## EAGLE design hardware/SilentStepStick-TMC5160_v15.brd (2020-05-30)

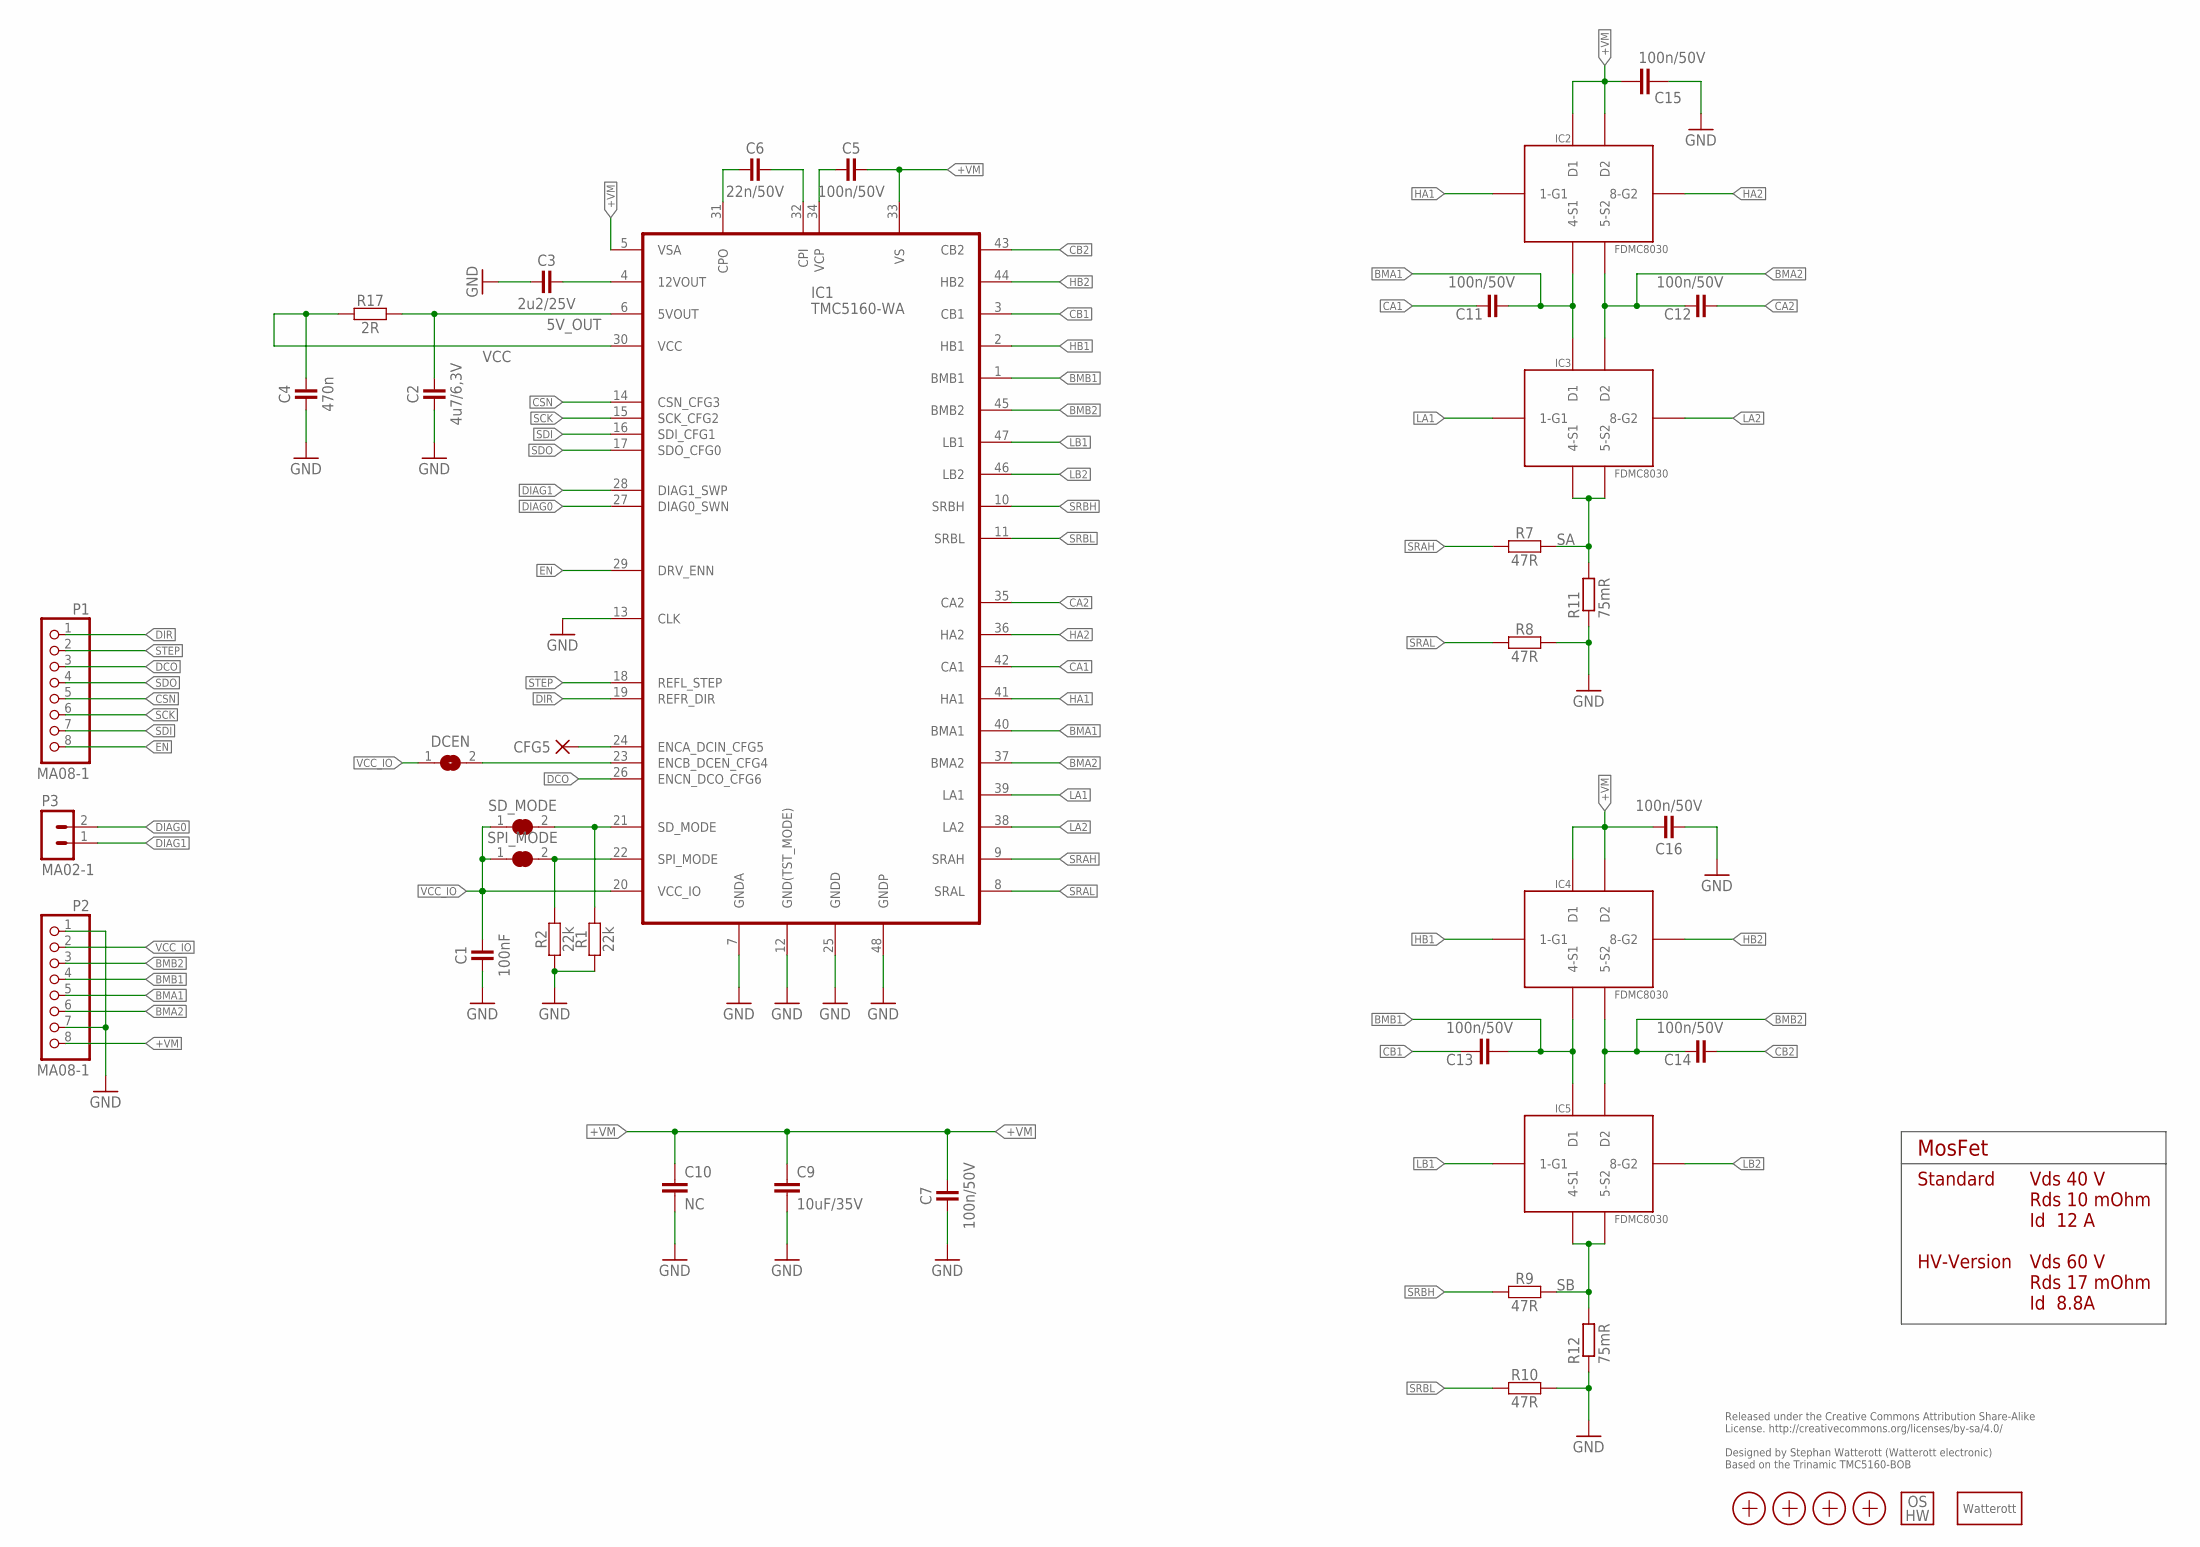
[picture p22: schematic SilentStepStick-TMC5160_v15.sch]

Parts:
C1: 100nF; C0402
C2: 4u7/6,3V; C0402
C3: 2u2/25V; C0402
C4: 470n; C0402
C5, C7, C11, C12, C13, C14, C15, C16: 100n/50V; C0402
C6: 22n/50V; C0402
C9: 10uF/35V; C0805
C10: NC; C0805
CFG5: PAD-0.7_NC
DCEN: JUMPER2-0402-NC; JUMPER2-0402_NC
IC1: TMC5160-WA; VQFN56(47)_8.0X8.0X0.9MM_0.5P_EP
IC2, IC3, IC4, IC5: FDMC8030; 8-POWERWDFN
LOGO1: LOGO_SPARK-2; SPARK_2MM
LOGO2: LOGO_OSHW-2; OSHW_2MM
P1, P2: MA08-1; 1X08-S
P3: MA02-1
R1, R2: 22k; C0201
R7, R8, R9, R10: 47R; C0402
R11, R12: 75mR; R1206
R17: 2R; C0402
SD_MODE: JUMPER2-0402-NC; JUMPER2-0402_NC
SPI_MODE: JUMPER2-0402-NC; JUMPER2-0402_NC
X1, X2, X3, X4: PASSER-04; PASSER_04MM

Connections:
5V_OUT: C2.2, IC1.6 (5VOUT), R17.2
+VM: C5.2, C7.2, C9.1, C10.1, C15.2, C16.2, IC1.5 (VSA), IC1.33 (VS), IC2.P$D1 (D1), IC2.P$D2 (D2), IC4.P$D1 (D1), IC4.P$D2 (D2), P2.8
BMA1: C11.1, IC1.40 (BMA1), IC2.P$4 (4-S1), IC3.P$D1 (D1), P2.5
BMA2: C12.2, IC1.37 (BMA2), IC2.P$5 (5-S2), IC3.P$D2 (D2), P2.6
BMB1: C13.1, IC1.1 (BMB1), IC4.P$4 (4-S1), IC5.P$D1 (D1), P2.4
BMB2: C14.2, IC1.45 (BMB2), IC4.P$5 (5-S2), IC5.P$D2 (D2), P2.3
CA1: C11.2, IC1.42 (CA1)
CA2: C12.1, IC1.35 (CA2)
CB1: C13.2, IC1.3 (CB1)
CB2: C14.1, IC1.43 (CB2)
CSN: IC1.14 (CSN_CFG3), P1.5
DCEN: DCEN.2, IC1.23 (ENCB_DCEN_CFG4)
DCIN: CFG5.1, IC1.24 (ENCA_DCIN_CFG5)
DCO: IC1.26 (ENCN_DCO_CFG6), P1.3
DIAG0: IC1.27 (DIAG0_SWN), P3.2
DIAG1: IC1.28 (DIAG1_SWP), P3.1
DIR: IC1.19 (REFR_DIR), P1.1
EN: IC1.29 (DRV_ENN), P1.8
GND: C1.1, C2.1, C3.1, C4.1, C7.1, C9.2, C10.2, C15.1, C16.1, IC1.7 (GNDA), IC1.12 (GND(TST_MODE)), IC1.13 (CLK), IC1.25 (GNDD), IC1.48 (GNDP), P2.1, P2.7, R1.1, R2.1, R8.2, R10.2, R11.1, R12.1
HA1: IC1.41 (HA1), IC2.P$1 (1-G1)
HA2: IC1.36 (HA2), IC2.P$8 (8-G2)
HB1: IC1.2 (HB1), IC4.P$1 (1-G1)
HB2: IC1.44 (HB2), IC4.P$8 (8-G2)
LA1: IC1.39 (LA1), IC3.P$1 (1-G1)
LA2: IC1.38 (LA2), IC3.P$8 (8-G2)
LB1: IC1.47 (LB1), IC5.P$1 (1-G1)
LB2: IC1.46 (LB2), IC5.P$8 (8-G2)
unnamed: C6.2, IC1.32 (CPI)
unnamed: C6.1, IC1.31 (CPO)
unnamed: C3.2, IC1.4 (12VOUT)
unnamed: C5.1, IC1.34 (VCP)
SA: IC3.P$4 (4-S1), IC3.P$5 (5-S2), R7.2, R11.2
SB: IC5.P$4 (4-S1), IC5.P$5 (5-S2), R9.2, R12.2
SCK: IC1.15 (SCK_CFG2), P1.6
SD: IC1.21 (SD_MODE), R1.2, SD_MODE.2
SDI: IC1.16 (SDI_CFG1), P1.7
SDO: IC1.17 (SDO_CFG0), P1.4
SPI: IC1.22 (SPI_MODE), R2.2, SPI_MODE.2
SRAH: IC1.9 (SRAH), R7.1
SRAL: IC1.8 (SRAL), R8.1
SRBH: IC1.10 (SRBH), R9.1
SRBL: IC1.11 (SRBL), R10.1
STEP: IC1.18 (REFL_STEP), P1.2
VCC: C4.2, IC1.30 (VCC), R17.1
VCC_IO: C1.2, DCEN.1, IC1.20 (VCC_IO), P2.2, SD_MODE.1, SPI_MODE.1

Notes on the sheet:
Released under the Creative Commons Attribution Share-Alike License. http://creativecommons.org/licenses/by-sa/4.0/ Designed by Stephan Watterott (Watterott electronic) Based on the Trinamic TMC5160-BOB
Vds 40 V Rds 10 mOhm Id 12 A Vds 60 V Rds 17 mOhm Id 8.8A
MosFet
Standard HV-Version

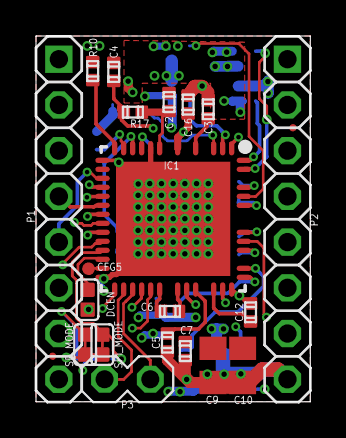
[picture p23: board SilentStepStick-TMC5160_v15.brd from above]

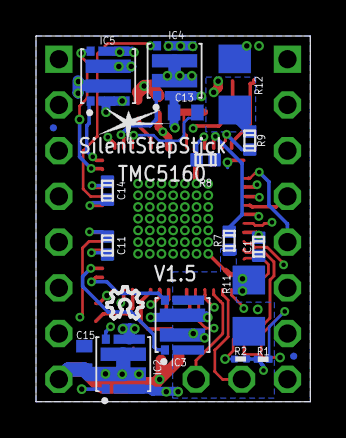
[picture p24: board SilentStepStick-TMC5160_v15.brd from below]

Board: 6 copper layers, 15.2 x 20.3 mm, 42 parts (20 on the bottom side), 45 nets.

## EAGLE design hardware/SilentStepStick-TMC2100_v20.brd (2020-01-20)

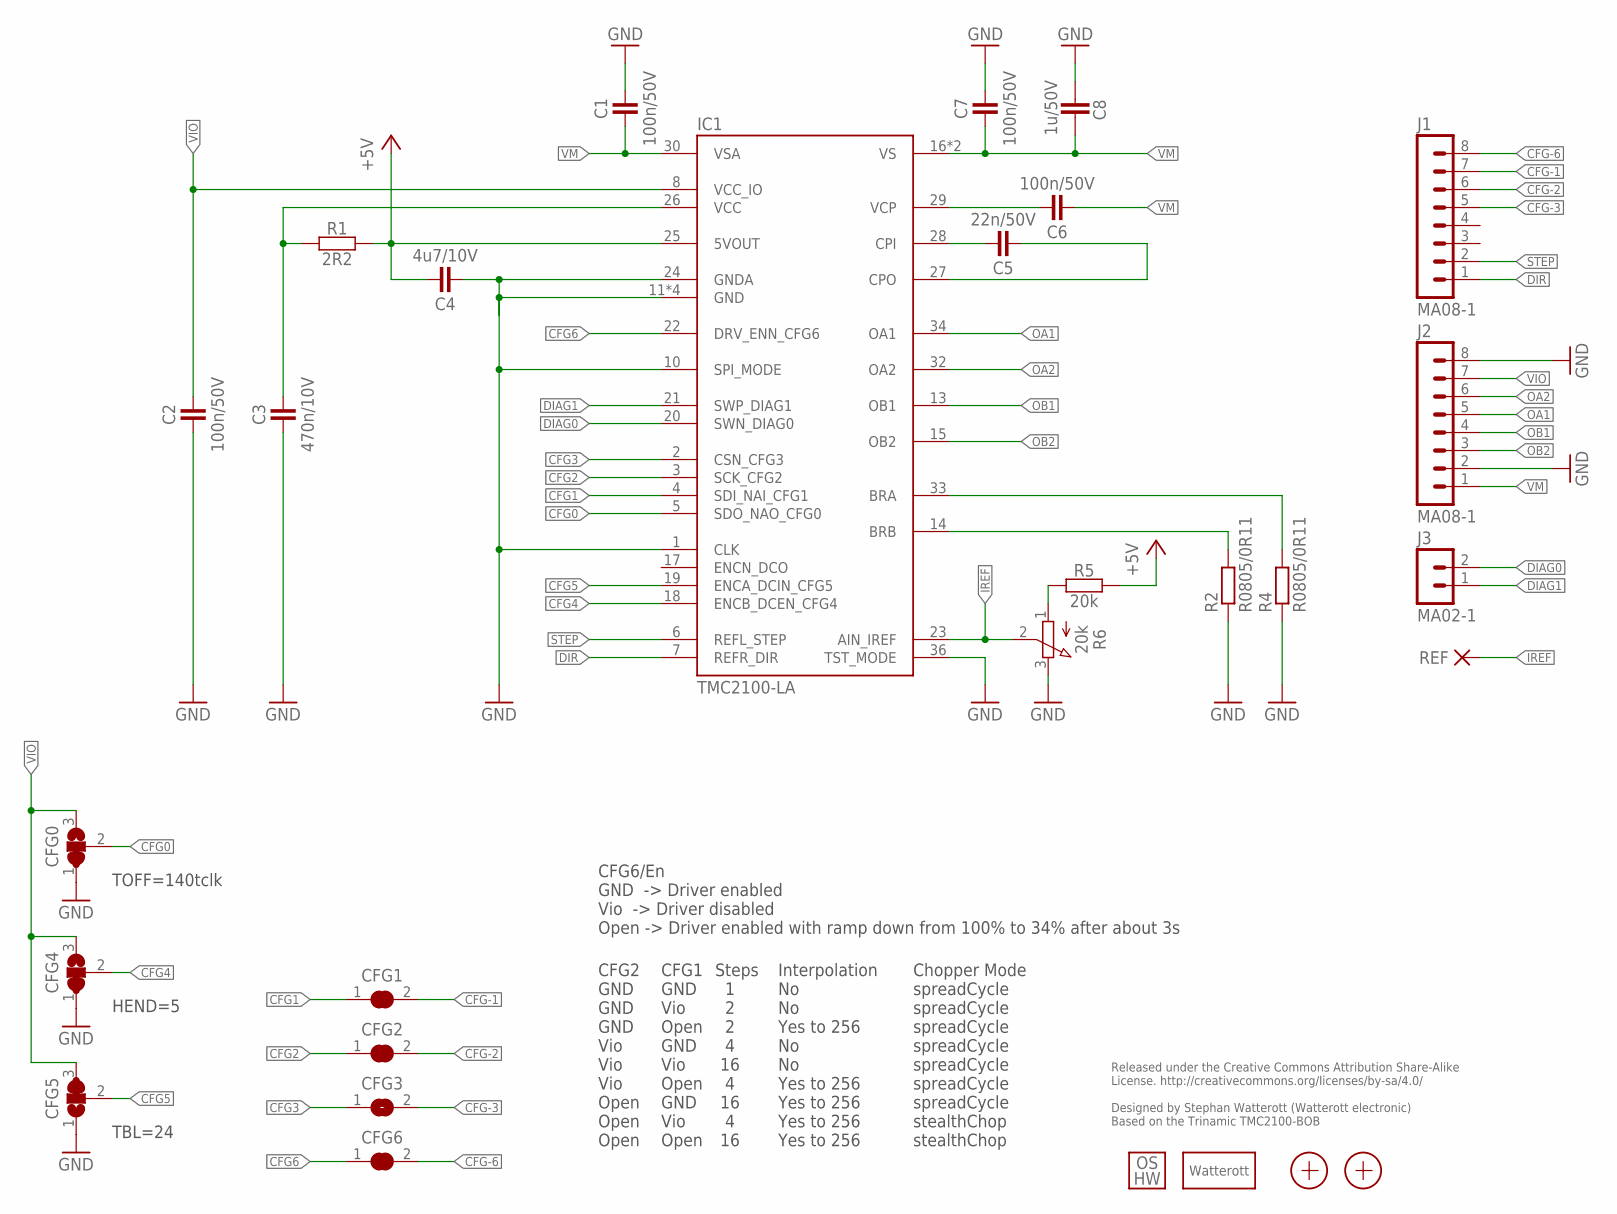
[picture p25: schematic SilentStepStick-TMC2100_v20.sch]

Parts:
C1, C2, C6, C7: 100n/50V; C0402
C3: 470n/10V; C0402
C4: 4u7/10V; C0402
C5: 22n/50V; C0402
C8: 1u/50V; C0603
CFG0, CFG4, CFG5: JUMPER3-0201
CFG1, CFG2, CFG3, CFG6: JUMPER2-0201
IC1: TMC2100-LA; QFN36-PAD
J1, J2: MA08-1
J3: MA02-1
LOGO3: LOGO_SPARK-2; SPARK_2MM
LOGO4: LOGO_OSHW-2; OSHW_2MM
R1: 2R2; C0402
R2, R4: R0805/0R11; M0805
R5: 20k; C0402
R6: 20k; POT_EVM3R
REF: PAD-0.6-1.1
X1, X2: PASSER-07; PASSER_07MM

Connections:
+5V: C4.2, IC1.25 (5VOUT), R1.2, R5.2
BRA: IC1.33 (BRA), R4.2
BRB: IC1.14 (BRB), R2.2
CFG0: CFG0.2, IC1.5 (SDO_NAO_CFG0)
CFG1: CFG1.1, IC1.4 (SDI_NAI_CFG1)
CFG2: CFG2.1, IC1.3 (SCK_CFG2)
CFG3: CFG3.1, IC1.2 (CSN_CFG3)
CFG4: CFG4.2, IC1.18 (ENCB_DCEN_CFG4)
CFG5: CFG5.2, IC1.19 (ENCA_DCIN_CFG5)
CFG6: CFG6.1, IC1.22 (DRV_ENN_CFG6)
CFG-1: CFG1.2, J1.7
CFG-2: CFG2.2, J1.6
CFG-3: CFG3.2, J1.5
CFG-6: CFG6.2, J1.8
CPI: C5.2, IC1.28 (CPI)
CPO: C5.1, IC1.27 (CPO)
DIAG0: IC1.20 (SWN_DIAG0), J3.2
DIAG1: IC1.21 (SWP_DIAG1), J3.1
DIR: IC1.7 (REFR_DIR), J1.1
GND: C1.2, C2.1, C3.1, C4.1, C7.2, C8.2, CFG0.1, CFG4.1, CFG5.1, IC1.1 (CLK), IC1.10 (SPI_MODE), IC1.11 (GND), IC1.12 (GND), IC1.24 (GNDA), IC1.35 (GND), IC1.36 (TST_MODE), IC1.TP (GND), J2.2, J2.8, R2.1, R4.1, R6.3 (E)
IREF: IC1.23 (AIN_IREF), R6.2 (S), REF.1
OA1: IC1.34 (OA1), J2.5
OA2: IC1.32 (OA2), J2.6
OB1: IC1.13 (OB1), J2.4
OB2: IC1.15 (OB2), J2.3
STEP: IC1.6 (REFL_STEP), J1.2
VCC: C3.2, IC1.26 (VCC), R1.1
VCP: C6.2, IC1.29 (VCP)
VIO: C2.2, CFG0.3, CFG4.3, CFG5.3, IC1.8 (VCC_IO), J2.7
VM: C1.1, C6.1, C7.1, C8.1, IC1.16 (VS), IC1.30 (VSA), IC1.31 (VS), J2.1
VREF1: R5.1, R6.1 (A)

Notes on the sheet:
Released under the Creative Commons Attribution Share-Alike License. http://creativecommons.org/licenses/by-sa/4.0/ Designed by Stephan Watterott (Watterott electronic) Based on the Trinamic TMC2100-BOB
CFG6/En GND -> Driver enabled Vio -> Driver disabled Open -> Driver enabled with ramp down from 100% to 34% after about 3s
CFG2 GND GND GND Vio Vio Vio Open Open Open
CFG1 GND Vio Open GND Vio Open GND Vio Open
Steps 1 2 2 4 16 4 16 4 16
Interpolation No No Yes to 256 No No Yes to 256 Yes to 256 Yes to 256 Yes to 256
Chopper Mode spreadCycle spreadCycle spreadCycle spreadCycle spreadCycle spreadCycle spreadCycle stealthChop stealthChop
TOFF=140tclk
HEND=5
TBL=24

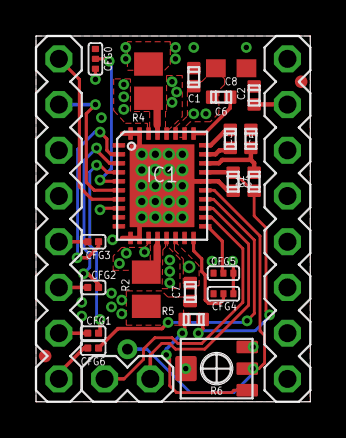
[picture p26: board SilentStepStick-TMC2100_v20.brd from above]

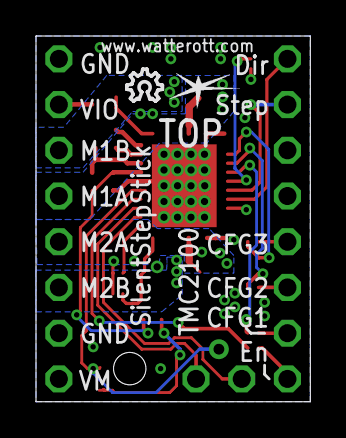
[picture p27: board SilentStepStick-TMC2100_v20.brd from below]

Board: 4 copper layers, 15.2 x 20.3 mm, 29 parts (2 on the bottom side), 31 nets.

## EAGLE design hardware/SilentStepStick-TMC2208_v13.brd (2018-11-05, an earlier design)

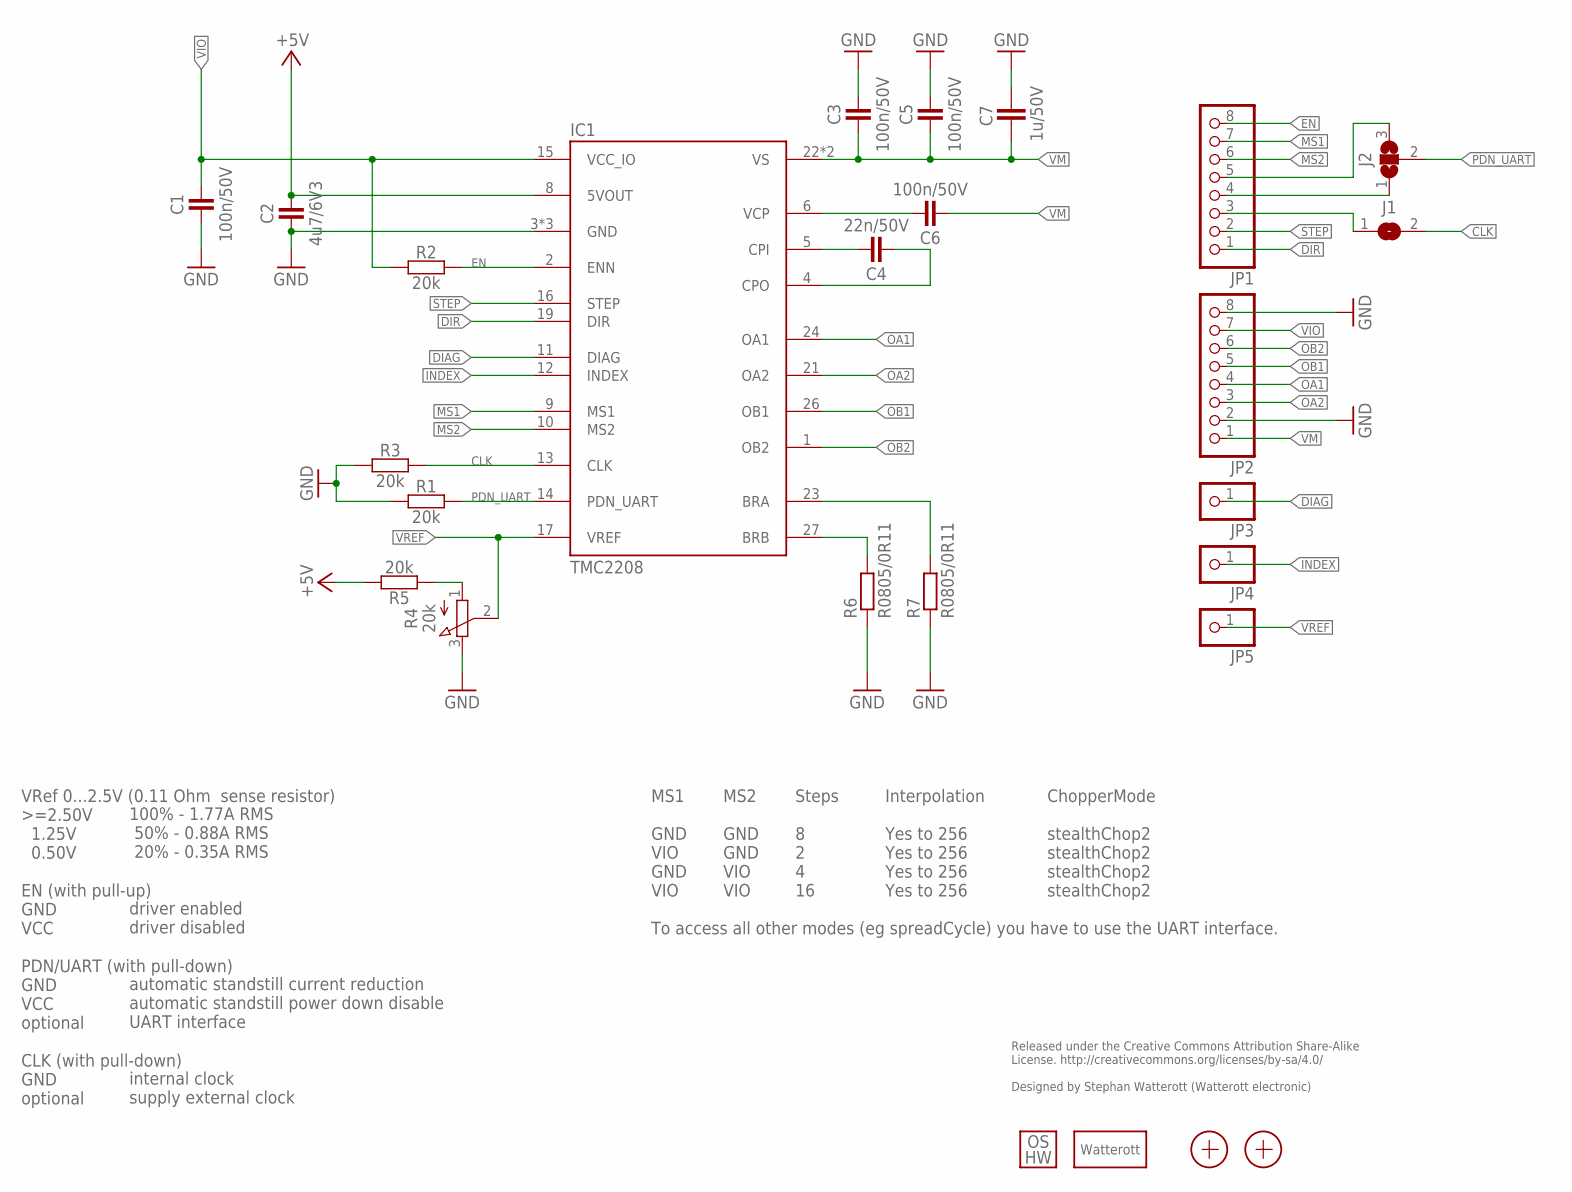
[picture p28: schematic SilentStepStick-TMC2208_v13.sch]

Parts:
C1, C3, C5, C6: 100n/50V; C0402
C2: 4u7/6V3; C0402
C4: 22n/50V; C0402
C7: 1u/50V; C0805
IC1: TMC2208; QFN28-PAD
J1: JUMPER2-0402
J2: JUMPER3-0402-NC; JUMPER3-0402_NC
JP1, JP2: PINHD-1X08_2.54-S; 1X08-S
JP3, JP4, JP5: PINHD-1X1; 1X01
LOGO3: LOGO_SPARK-2; SPARK_2MM
LOGO4: LOGO_OSHW-2; OSHW_2MM
R1, R2, R3, R5: 20k; C0402
R4: 20k; POT_EVM3R
R6, R7: R0805/0R11; M0805
X1, X2: PASSER-04; PASSER_04MM

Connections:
+5V: C2.2, IC1.8 (5VOUT), R5.2
BRA: IC1.23 (BRA), R7.2
BRB: IC1.27 (BRB), R6.2
CLK: IC1.13 (CLK), J1.2, R3.2
CPI: C4.2, IC1.5 (CPI)
CPO: C4.1, IC1.4 (CPO)
DIAG: IC1.11 (DIAG), JP3.1
DIR: IC1.19 (DIR), JP1.1
EN: IC1.2 (ENN), JP1.8, R2.2
GND: C1.1, C2.1, C3.2, C5.2, C7.2, IC1.3 (GND), IC1.18 (GND), IC1.TP (GND), JP2.2, JP2.8, R1.1, R3.1, R4.3 (E), R6.1, R7.1
INDEX: IC1.12 (INDEX), JP4.1
MS1: IC1.9 (MS1), JP1.7
MS2: IC1.10 (MS2), JP1.6
unnamed: J2.3, JP1.5
unnamed: J1.1, JP1.3
unnamed: J2.1, JP1.4
OA1: IC1.24 (OA1), JP2.4
OA2: IC1.21 (OA2), JP2.3
OB1: IC1.26 (OB1), JP2.5
OB2: IC1.1 (OB2), JP2.6
PDN_UART: IC1.14 (PDN_UART), J2.2, R1.2
STEP: IC1.16 (STEP), JP1.2
VCP: C6.2, IC1.6 (VCP)
VIO: C1.2, IC1.15 (VCC_IO), JP2.7, R2.1
VM: C3.1, C5.1, C6.1, C7.1, IC1.22 (VS), IC1.28 (VS), JP2.1
VREF: IC1.17 (VREF), JP5.1, R4.2 (S)
VREF1: R4.1 (A), R5.1

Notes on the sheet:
Released under the Creative Commons Attribution Share-Alike License. http://creativecommons.org/licenses/by-sa/4.0/ Designed by Stephan Watterott (Watterott electronic)
VRef 0...2.5V (0.11 Ohm sense resistor) >=2.50V 1.25V 0.50V EN (with pull-up) GND VCC PDN/UART (with pull-down) GND VCC optional CLK (with pull-down) GND optional
100% - 1.77A RMS 50% - 0.88A RMS 20% - 0.35A RMS driver enabled driver disabled automatic standstill current reduction automatic standstill power down disable UART interface internal clock supply external clock
MS1 GND VIO GND VIO To access all other modes (eg spreadCycle) you have to use the UART interface.
MS2 GND GND VIO VIO
Steps 8 2 4 16
Interpolation Yes to 256 Yes to 256 Yes to 256 Yes to 256
ChopperMode stealthChop2 stealthChop2 stealthChop2 stealthChop2

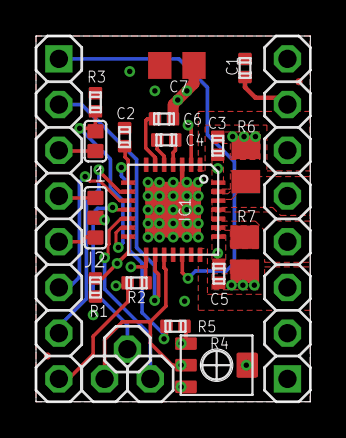
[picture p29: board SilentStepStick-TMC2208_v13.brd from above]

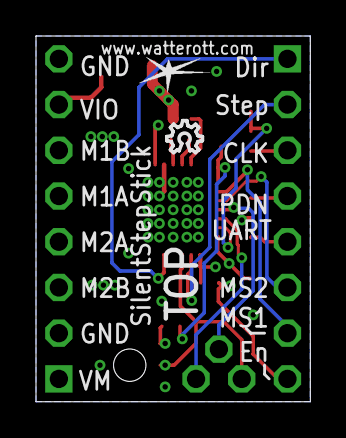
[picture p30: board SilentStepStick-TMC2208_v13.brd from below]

Board: 4 copper layers, 15.2 x 20.3 mm, 26 parts (2 on the bottom side), 27 nets.

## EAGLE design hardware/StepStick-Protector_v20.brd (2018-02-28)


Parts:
C1: 10u/50V; C1210
D1+, D1-, D2+, D2-, D3+, D3-, D4+, D4-, D5: S310FA; SOD123
IC1: STEPSTICK-TP; STEPSTICK_TP
J1: JUMPER2-0603-NC; JUMPER2-0603_NC
LOGO1: OSHW_LOGOX0070; OSHW_6X70
LOGO3: LOGO_SPARK-2; SPARK_2MM
X1, X2: PASSER

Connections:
GND: C1.1, D1-.A, D2-.A, D3-.A, D4-.A, IC1.GND@1 (GND), IC1.GND@2 (GND), J1.1
M1A: D1+.A, D1-.C, IC1.M1A
M1B: D2+.A, D2-.C, IC1.M1B
M2A: D3+.A, D3-.C, IC1.M2A
M2B: D4+.A, D4-.C, IC1.M2B
unnamed: IC1.CFG1 (CFG1/SDI), J1.2
VIO: D5.A, IC1.VIO
VM: C1.2, D1+.C, D2+.C, D3+.C, D4+.C, D5.C, IC1.VM

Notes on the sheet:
Released under the Creative Commons Attribution Share-Alike License
http://creativecommons.org/licenses/by-sa/4.0/
Designed by Andreas Watterott (Watterott electronic)
Schottky Diodes 3A/100V
J1 enables spreadCycle on TMC2100. 1/16 stealthChop: CFG1=open CFG2=open CFG3=open 1/16 spreadCycle: CFG1=GND CFG2=open CFG3=open



Board: 2 copper layers, 15.2 x 20.3 mm, 16 parts (3 on the bottom side), 8 nets.

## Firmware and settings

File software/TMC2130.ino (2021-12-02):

/*
  SilentStepStick TMC2130 Example
  Rsense: 0.11 Ohm

  Other examples/libraries can be found here:
  https://github.com/teemuatlut/TMCStepper
  https://github.com/trinamic/TMC-API
  https://github.com/janelia-arduino/TMC2130
  https://github.com/makertum/Trinamic_TMC2130

  Example source code free to use.
  Further information: https://learn.watterott.com/license/
*/

#include <SPI.h>

// Note: You also have to connect GND, 5V/VIO and VM.
//       A connection diagram can be found in the schematics.
#define EN_PIN    7 //enable (CFG6)
#define DIR_PIN   8 //direction
#define STEP_PIN  9 //step

#define CS_PIN   10 //CS chip select
#define MOSI_PIN 11 //SDI/MOSI (ICSP: 4, Uno: 11, Mega: 51)
#define MISO_PIN 12 //SDO/MISO (ICSP: 1, Uno: 12, Mega: 50)
#define SCK_PIN  13 //CLK/SCK  (ICSP: 3, Uno: 13, Mega: 52)

//TMC2130 registers
#define WRITE_FLAG     (1<<7) //write flag
#define READ_FLAG      (0<<7) //read flag
#define REG_GCONF      0x00
#define REG_GSTAT      0x01
#define REG_IHOLD_IRUN 0x10
#define REG_CHOPCONF   0x6C
#define REG_COOLCONF   0x6D
#define REG_DCCTRL     0x6E
#define REG_DRVSTATUS  0x6F

uint8_t tmc_write(uint8_t cmd, uint32_t data)
{
  uint8_t s;

  digitalWrite(CS_PIN, LOW);

  s = SPI.transfer(cmd);
  SPI.transfer((data>>24UL)&0xFF);
  SPI.transfer((data>>16UL)&0xFF);
  SPI.transfer((data>> 8UL)&0xFF);
  SPI.transfer((data>> 0UL)&0xFF);

  digitalWrite(CS_PIN, HIGH);

  return s;
}

uint8_t tmc_read(uint8_t cmd, uint32_t *data)
{
  uint8_t s;

  tmc_write(cmd, 0UL); //set read address

  digitalWrite(CS_PIN, LOW);

  s = SPI.transfer(cmd);
  *data  = SPI.transfer(0x00)&0xFF;
  *data <<=8;
  *data |= SPI.transfer(0x00)&0xFF;
  *data <<=8;
  *data |= SPI.transfer(0x00)&0xFF;
  *data <<=8;
  *data |= SPI.transfer(0x00)&0xFF;

  digitalWrite(CS_PIN, HIGH);

  return s;
}

void setup()
{
  //set pins
  pinMode(EN_PIN, OUTPUT);
  digitalWrite(EN_PIN, HIGH); //deactivate driver (LOW active)
  pinMode(DIR_PIN, OUTPUT);
  digitalWrite(DIR_PIN, LOW); //LOW or HIGH
  pinMode(STEP_PIN, OUTPUT);
  digitalWrite(STEP_PIN, LOW);

  pinMode(CS_PIN, OUTPUT);
  digitalWrite(CS_PIN, HIGH);
  pinMode(MOSI_PIN, OUTPUT);
  digitalWrite(MOSI_PIN, LOW);
  pinMode(MISO_PIN, INPUT);
  digitalWrite(MISO_PIN, HIGH);
  pinMode(SCK_PIN, OUTPUT);
  digitalWrite(SCK_PIN, LOW);

  //init serial port
  Serial.begin(9600); //init serial port and set baudrate
  while(!Serial); //wait for serial port to connect (needed for Leonardo only)
  Serial.println("\nStart...");

  //init SPI
  SPI.begin();
  //SPI.setDataMode(SPI_MODE3); //SPI Mode 3
  //SPI.setBitOrder(MSBFIRST); //MSB first
  //SPI.setClockDivider(SPI_CLOCK_DIV128); //clk=Fcpu/128
  SPI.beginTransaction(SPISettings(1000000UL, MSBFIRST, SPI_MODE3));

  //set TMC2130 config
  tmc_write(WRITE_FLAG|REG_GCONF,      0x00000001UL); //voltage on AIN is current reference
  tmc_write(WRITE_FLAG|REG_IHOLD_IRUN, 0x00001010UL); //IHOLD=0x10, IRUN=0x10
  tmc_write(WRITE_FLAG|REG_CHOPCONF,   0x00008008UL); //native 256 microsteps, MRES=0, TBL=1=24, TOFF=8
  //tmc_write(WRITE_FLAG|REG_CHOPCONF,   0x01008008UL); //128 microsteps, MRES=0, TBL=1=24, TOFF=8
  //tmc_write(WRITE_FLAG|REG_CHOPCONF,   0x02008008UL); // 64 microsteps, MRES=0, TBL=1=24, TOFF=8
  //tmc_write(WRITE_FLAG|REG_CHOPCONF,   0x03008008UL); // 32 microsteps, MRES=0, TBL=1=24, TOFF=8
  //tmc_write(WRITE_FLAG|REG_CHOPCONF,   0x04008008UL); // 16 microsteps, MRES=0, TBL=1=24, TOFF=8
  //tmc_write(WRITE_FLAG|REG_CHOPCONF,   0x05008008UL); //  8 microsteps, MRES=0, TBL=1=24, TOFF=8
  //tmc_write(WRITE_FLAG|REG_CHOPCONF,   0x06008008UL); //  4 microsteps, MRES=0, TBL=1=24, TOFF=8
  //tmc_write(WRITE_FLAG|REG_CHOPCONF,   0x07008008UL); //  2 microsteps, MRES=0, TBL=1=24, TOFF=8
  //tmc_write(WRITE_FLAG|REG_CHOPCONF,   0x08008008UL); //  1 microsteps, MRES=0, TBL=1=24, TOFF=8

  //outputs on (LOW active)
  digitalWrite(EN_PIN, LOW);
}

void loop()
{
  static uint32_t last_time=0;
  uint32_t ms = millis();
  uint32_t data;
  uint8_t s;
    
  if((ms-last_time) > 1000) //run every 1s
  {
    last_time = ms;

    //show REG_GSTAT
    s = tmc_read(REG_GSTAT, &data);
    Serial.print("GSTAT:     0x0");
    Serial.print(data, HEX);
    Serial.print("\t - ");
    Serial.print("Status: 0x");
    Serial.print(s, HEX);
    if(s & 0x01) Serial.print(" reset");
    if(s & 0x02) Serial.print(" error");
    if(s & 0x04) Serial.print(" sg2");
    if(s & 0x08) Serial.print(" standstill");
    Serial.println(" ");

    //show REG_DRVSTATUS
    s = tmc_read(REG_DRVSTATUS, &data);
    Serial.print("DRVSTATUS: 0x");
    Serial.print(data, HEX);
    Serial.print("\t - ");
    Serial.print("Status: 0x");
    Serial.print(s, HEX);
    if(s & 0x01) Serial.print(" reset");
    if(s & 0x02) Serial.print(" error");
    if(s & 0x04) Serial.print(" sg2");
    if(s & 0x08) Serial.print(" standstill");
    Serial.println(" ");
  }

  //make steps
  digitalWrite(STEP_PIN, HIGH);
  delayMicroseconds(10);
  digitalWrite(STEP_PIN, LOW);
  delayMicroseconds(10);
}

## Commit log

2017-03-01 added StepStick-Tester
    [StepStick-Tester_v10.brd, StepStick-Tester_v10.sch]
2017-03-01 renamed files
    [SilentStepStick-TMC2100_v10.brd, SilentStepStick-TMC2100_v10.sch, SilentStepStick-TMC2100_v11.brd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]
2017-04-10 updated layout
    [SilentStepStick-TMC2208_v10.brd]
2017-04-10 added SilentStepStick TMC2208 v1.1
    [SilentStepStick-TMC2208_v11.brd, SilentStepStick-TMC2208_v11.sch]
2017-04-12 updated schematics
    [StepStick-Tester_v10.sch]
2017-12-02 added SilentStepStick TMC2100 v1.3
    [SilentStepStick-TMC2100_v13.brd, SilentStepStick-TMC2100_v13.sch, SilentStepStick-TMC2100_v13_5V.brd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]
2018-01-13 updated schematics and layout files
    [SilentStepStick-TMC2130_v11.brd, SilentStepStick-TMC2130_v11.sch, SilentStepStick-TMC2208_v12.brd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]
2018-02-28 added v2 Protector
    [StepStick-Protector_v20.brd, StepStick-Protector_v20.sch]
2018-11-05 added TMC2208 v1.3
    [SilentStepStick-TMC2208_v13.brd, SilentStepStick-TMC2208_v13.sch]
2019-02-24 added TMC5160
    [SilentStepStick-TMC5160_v13.brd, SilentStepStick-TMC5160_v13.sch]
2019-05-11 added TMC2100 5V v2.0
    [SilentStepStick-TMC2100_v20_5V.brd, SilentStepStick-TMC2100_v20_5V.sch]
2019-06-11 added TMC2209 v2.0
    [SilentStepStick-TMC2209_v20.brd, SilentStepStick-TMC2209_v20.sch]
2019-07-05 added TMC2130 v2.0
    [SilentStepStick-TMC2130_v20.brd, SilentStepStick-TMC2130_v20.sch]
2019-07-05 updated silkscreen
    [SilentStepStick-TMC2100_v20_5V.brd]
2019-07-15 added SilentStepStick TMC5160 v1.4
    [SilentStepStick-TMC5160_v14.brd, SilentStepStick-TMC5160_v14.sch]
2020-01-20 added TMC2100 v2
    [SilentStepStick-TMC2100_v20.brd, SilentStepStick-TMC2100_v20.sch]
2020-05-30 added TMC5160 v1.5
    [SilentStepStick-TMC5160_v15.brd, SilentStepStick-TMC5160_v15.sch]
2021-09-27 added TMC2208 v2.0
    [SilentStepStick-TMC2208_v20.brd, SilentStepStick-TMC2208_v20.sch]
2022-02-27 corrected Vref and current values
    [SilentStepStick-TMC2208_v10.sch, SilentStepStick-TMC2208_v11.sch, SilentStepStick-TMC2208_v12.sch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]
